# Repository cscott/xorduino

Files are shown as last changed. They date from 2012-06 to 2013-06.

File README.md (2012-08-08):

This is an Open Hardware peripheral for the OLPC XO-1/1.5/1.75/4.

The files are created using Eagle 6.2.0 on Linux and the SparkFun footprint
libraries.

Strong inspiration drawn from the following Open Hardware designs (thanks for
sharing!):
* The Arduino Leonardo (arduino-compatible ATmega32U4 design)
* SparkFun's ATmega32U4 breakout <http://www.sparkfun.com/products/11117>
  for figuring out which parts of the Leonardo design are actually
  mandatory
* SparkFun's Scratch Sensor Board-compatible PicoBoard
    <http://www.sparkfun.com/products/10311>

Some notes:

0. This board integrates Arduino, Scratch Sensor Board, and turtle robot
   functionality.  There are many optional parts: if you want to build
   just the Arduino, you may; if you want to populate the robot functionality
   but not the sensor board, that's fine, too.  If you populate the
   peripherals but not the ATmega32u4 processor, this makes a splendid
   "shield" for the XO Stick -- one way to amortize the cost of
   the robot functionality is to have just one XOrduino-bot shield per
   classroom, while still giving the kids their own XO Stick "brains"
   which they can mount on top of it.

    The "bot" features of the board include a current-limited motor driver,
   two bump switches at the front of the board, and two optical sensors
   for measuring motor rotation, allowing the user to write code like
   "rotate left 90 degrees" instead of "rotate left 2 seconds", which
   experimentally kids find much harder to understand.  The XOrduino
   board mounts on a Tamiya Twin Motor Gearbox (part #70097), and there's
   a mounting hole for a ~25mm long standoff to serve as a front skid.

    The motors are set up to draw 1A max, which matches the power source
   ability of the XO's USB ports.  The USB standard only allows 500mA
   draw, which would require adjusting F1 and RN7.

1. Many of the Leonardo design's components are optional in a
   lowest-possible-cost design, for a number of different reasons:
   a) USB port protection which is already included on the XO
      motherboard,
   b) ESD and protection diodes (helpful but not required),
   c) bypass caps and ferrites for less noise on analog signals
      (helpful but not required).
   Wherever possible I've included the pads anyway, so that less
   budget-conscious users can populate these components.  At times
   this has required jumper traces which you need to cut if you
   decide to populate the optional components.

2. I eliminated the multi-way 3.3V/5V internal/external power supply
   functionality of the Arduino to save cost.  The XOrduino is 5V
   only, powered by the USB port.  The Arduino "3.3V" pin on the
   shield connector is left disconnected.  I've replaced this with
   a lower cost step-up regulator, allowing "bot" users to power
   the XOrduino with a 3-cell (4.5v) battery pack.  Again, all
   these components are optional: the XOrduino will run fine
   powered by its USB tether.

3. The first version of this board used a large number of through-hole
   parts.  This revision is less afraid of surface mount parts (since
   the ATmega32U4 is only available in an SMT package anyway), which
   save board space and lower BOM cost.  I'm attempting to make the
   XOrduino local-assembly-friendly, so I surface mount footprints are
   as large as possible: all discrete components are 0805 or larger.
   Like the XO Stick, this has been routed as a two layer board to
   lower reproduction costs, although if you fabricate with a 4-layer
   board you will get more robust power and ground planes.

    One possibly-controversial change in this version is to use
   surface mount resistor arrays to reduce part count and BOM cost;
   they may turn out to be too small to hand assemble.  We'll see.

4. I made this Scratch Sensor Board compatible.  Even though many of
   the scratch sensors are redudant on the XO (it has a microphone
   already, and the XO-1.75 includes an ambient light sensor), they
   gain new relevance in the "turtle bot" mode -- they make it easy to
   build a standalone robot which is "afraid of light", "stops when
   you clap", etc.  The scratch community has a large number of
   interesting examples based around the Scratch Sensor
   Board/Picoboard, many of which can use the 4 additional channels
   provided by the XOrduino ("color etch-a-sketch", for example, with
   knobs for X, Y, color, and line width).  I used 3.5mm jacks instead
   of the Picoboard-standard 2.5mm jacks in order to be compatible
   with probes built for the XO; I hope that was a good choice.

    See https://github.com/osbock/ScratchSensors for an arduino sketch
   to support the Scratch Sensor board functionality; it might be nicer
   to integrate this into the bootloader so that it's "always there".

5. There's a USB plug integrated with the PCB with break-off tabs to
   increase the thickness to the USB standard 1.6mm.  There are pads
   for a through-hole USB mini-B connector and a more-standard surface
   mount USB micro-B connector, but they are rather expensive (~$1).

    When the discrete connector is populated, it leaves the USB
   signals and power/gnd exposed on big metal tabs, which could be
   non-ideal.  Certainly you shouldn't plug in to more than one jack
   at a time.

  -- C. Scott Ananian, 2012-06-09, revised 2012-07-30, 2012-08-08.

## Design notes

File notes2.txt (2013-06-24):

Notes/todo for XOrduino2 design:
.- drill second mounting hole
.- drill skid hole
   3mm hole, 1mm front front end, centered (53mm wide, center is 26.5mm)
   make hole bigger to accomodate 6-32 screw: digikey 1903EK-ND
   slightly longer would be better
   existing holes are 3.2mm; .12598425"
   24438K-ND is $0.4101 (qty 100), M3, 25mm long
x- wire up L293
x- wire up 7805
.- wire up limit switches
.- wire up optoisolators
research TCRT1000, we only need 2-3mm now. slightly taller shoulder?
downward looker? paint top of gear.
.- servo connection? 4.8V servo
x- bidirectional led instead of ambient light sensor
.- remove external pull-up, use internal pullup, change to 3.5mm jack
   to be compatible w/ XO
.- current limit should be 300-400mA per motor, change USB fuse to match
   XO limit is 1.0-1.1A. (USB spec is 500mA, though)
.- no-hole version of bumper switch footprint
.- switch to array of solder jumpers for A0-A5 routing
.- put via in solder jumper footprint?
.- rotate motor power 90 degrees?
.- via in switcher
.- shift ICP jack to right
.- SMT LEDs? 0805, @ $0.06 red/green
.- look at diode placement
.- move switcher to front side?
.- add variant of usb micro w/ breaks out to vias?
.- alt version of 3mm LED w/ straight line on one side
x- split current limit resistors
.- minimize # of solder jumpers
.- battery input is Vin, use something else (Vm) for wire-or'ed signal.
.- change width of polygons to non-zero (switcher done, h-bridge still to do)
x- remove center dot on uC footprint
.- fault LED SMT and placed next to resistor on top of bridge
.- swap ISP and photosensor location
.- fix usb micro broken out
 - divide up tab area into 4 equal parts (2.1" tall, usb is .48")
   measure width of router bit... looks like we only have .04" kerf =(
x- bottom | top - seems to be best?
.- fixup silkscreen on USB mini footprint (do DRC w/ solder mask enabled)
 - fixup 1n4148 silkscreen and z1/z2 silkscreen
 - power switch

battery backup circuit:
 dedicated: 	ICL7673CPAZ-ND ($1.40), 296-10879-1-ND ($1.50)
http://www.linear.com/product/LTC4411
LTC4411ES5#TRMPBF-ND ($3.12) linear says $1.66 qty 1000
(see also LTC4410 w/ external FET)
something like LP38693, the VEN signal can be tied to VIN
 XXX but really want VEN = !VUSB

better: just put diode between 5v regulator and 5v supply, run at 4.8V
from battery, run at 5v w/ usb power. (or run at 3.3V from battery?)

or even better: just run i/o at 4.5v when running from usb power?
(schottkey diode between vusb and +5V)
run everything from 6V from battery (no regulator)
are there quad schottkey diodes? SD103ATW-FDICT-ND $0.2039 qty 100
  (0.08 premium)

ATmega32U4 uses 16mA max
motor driver cuts out at 2.6V
power option 1:
 4.5V battery, normal diode-OR, NJU7261U50-TE1CT-ND step up (1-5V) $0.40 qty 100
               two diodes for 6V battery version
               run VM from diode-OR voltage (ie, 3.9V or 5.8V)
 needs 22uF cap x 2, 100uH inductor 587-2048-1-ND (50mA, $0.0665 qty 100)
                                or  587-2055-1-ND (80mA, $0.0980 qty 100)
    battery holder wire lead BC3AAW-ND $1.06 qty 100
 
 alternatively 	1028-1077-1-ND (richtek RT9261A-50GB) is $0.65 qty 100
  needs 100uH inductor, 1N5819 diode, and 22uF cap.

new motor driver! 296-29434-1-ND ($2.204 qty 100)
 (also keep an eye on 869-1287-1-ND ($1.7718 qty 100)
                  and 296-28165-1-ND (DRV8830) )
usb micro: $0.30320 SMD
609-4050-1-ND $0.505 SMD more solderable.  no good thru-hole version

to buy:
 digikey:
  wirewrap tool 	K105-ND
  30 awg wire stripper JIC-2030-ND (pliers form, $9.10)
                       K512-ND (cut and strip tool, $52.50)
                       K503-ND ($34.60)
  ATTINY861A-PU-ND
  new photosensors
    QRE1113GRCT-ND (smd)
    QRE1113-ND (4-DIP)
  3mm spacer? 24438K-ND
    H744-ND (M3x12 screw)
  more stackable headers?
  usb micro connector 609-4050-1-ND
  motor driver 296-29434-1-ND
  3x Schottkey: SD103ATW-FDICT-ND
  screw terminal A98334-ND
  single schottkey for prototyping?
   LSM115JE3/TR13CT-ND has Vf of 0.22 V
  new 1/8" jack: CP1-3523N-ND
 sparkfun:
  tooth wheels?
  flux pen
  solder

optosensor: consider:
751-1031-ND $0.7424 (qty 100) -- original part
QRE1113GRCT-ND $0.5838 (qty 100)
475-1239-1-ND $1.2254 (qty 100) -- logic level out
ambient light sensor
1080-1019-ND $0.29760 (qty 100) good match for 50uA light current of original part

--------------------
Partlist

Exported from XOrduino2.sch at 7/30/12 12:38 PM

EAGLE Version 6.2.0 Copyright (c) 1988-2012 CadSoft

Assembly variant: 

Part     Value             Device               Package               Library                    Sheet DigiKey Package Price (qty 100)

C1       18p               CAP0805                        0805                           SparkFun-Passives          1 311-1102-1-ND 0805" $0.02860
C2       18p               CAP0805                        0805                           SparkFun-Passives          1
C3       100n              CAP0805                        0805                           SparkFun-Passives          1 311-1361-1-ND 0805" $0.01410
C4       100n              CAP0805                        0805                           SparkFun-Passives          1
C5       100n              CAP0805                        0805                           SparkFun-Passives          1
C6       100n              CAP0805                        0805                           SparkFun-Passives          1
C7       100n              CAP0805                        0805                           SparkFun-Passives          1
C8       1uF               CAP0805                        0805                           SparkFun-Passives          1 445-1589-1-ND 0805" $0.01150
C9       1uF               CAP0805                        0805                           SparkFun-Passives          1
C10      0.22uF            CAP0805                        0805                           SparkFun-Passives          1 587-1306-1-ND 0805" $0.03800
C11      0.33uF            CAP0805                        0805                           SparkFun-Passives          1 445-1356-1-ND 0805" $0.06300 (!)
C12      10uF              CAP0805                        0805                           SparkFun-Passives          2 445-1371-1-ND 0805" $0.04990
C13      22uF              CAP1206                        1206                           SparkFun-Passives          1 587-1356-1-ND 1206" $0.10000
C14      22uF              CAP1206                        1206                           SparkFun-Passives          2
C15      0.01uF            CAP0805                        0805                           SparkFun-Passives          2 490-1664-1-ND 0805" $0.01420
D1       1N4148            DIODE1N4148                    DIODE-1N4148                   SparkFun-DiscreteSemi      1 1N4148FS-ND, 200mA  DO-35 $0.03690
D2       1N4148            DIODE1N4148                    DIODE-1N4148                   SparkFun-DiscreteSemi      1
D3       1A Schottkey      DIODE-SCHOTTKY_                SMA-DIODE                      SparkFun-DiscreteSemi      2 641-1014-1-ND SMA  $0.15140
D4       1A Schottkey      DIODE-SCHOTTKY_                SMA-DIODE                      SparkFun-DiscreteSemi      2
F1       0ZCC0110FF2C 1.1A L-EUL1812                      L1812                          rcl                        1 507-1363-1-ND 1812" $0.16150
                                                                                                                      S1012EC-40-ND       $0.37800 (1x40, for H1/H2/H3/H4/JP12)
H1       10x1F-H8.5        PINHD-1X10                     1X10                           SmartPrj                   1
H2       8x1F-H8.5         PINHD-1X8                      1X08                           SmartPrj                   1
H3       8x1F-H8.5         PINHD-1X8                      1X08                           SmartPrj                   1
H4       6x1F-H8.5         PINHD-1X6                      1X06                           SmartPrj                   1
H5       ICSP              PINHD-2X3                      2X03                           SmartPrj                   1 609-3218-ND         $0.1778
J1       2.5mm             AUDIO-JACK                     MJ-3523-SMT                    xorduino                   1 CP-3523MJCT-ND      $0.79610
J2       2.5mm             AUDIO-JACK                     MJ-3523-SMT                    xorduino                   1
J3       2.5mm             AUDIO-JACK                     MJ-3523-SMT                    xorduino                   1
J4       2.5mm             AUDIO-JACK                     MJ-3523-SMT                    xorduino                   1
J5       Batt In           M02PTH                         1X02                           SparkFun-Connectors        2 BC3AAW-ND           $1.06000
J6       MOT R             M023.5MM                       SCREWTERMINAL-3.5MM-2          SparkFun                   2 A98036-ND           $0.18010
J7       MOT L             M023.5MM                       SCREWTERMINAL-3.5MM-2          SparkFun                   2
JP1      N/C               SOLDERJUMPERNOCONFLICT         SJ-2S-TRACE-NOCONFLICT         xorduino                   2 n/a
JP2      N/C               SOLDERJUMPERNOCONFLICT         SJ-2S-TRACE-NOCONFLICT         xorduino                   1
JP3      N/C               SOLDERJUMPERNOCONFLICT         SJ-2S-TRACE-NOCONFLICT         xorduino                   1
JP4      N/C               SOLDERJUMPERNOCONFLICT         SJ-2S-TRACE-NOCONFLICT         xorduino                   1
JP5      N/C               SOLDERJUMPERNOCONFLICT         SJ-2S-TRACE-NOCONFLICT         xorduino                   1
JP6      N/C               SOLDERJUMPERNOCONFLICT         SJ-2S-TRACE-NOCONFLICT         xorduino                   1
JP7      N/C               SOLDERJUMPERBOT-VIA-NOCONFLICT SJ-2S-BOT-TRACE-VIA-NOCONFLICT xorduino                   1
JP8      N/C               SOLDERJUMPERBOT-VIA-NOCONFLICT SJ-2S-BOT-TRACE-VIA-NOCONFLICT xorduino                   1
JP9      N/C               SOLDERJUMPERBOT-VIA-NOCONFLICT SJ-2S-BOT-TRACE-VIA-NOCONFLICT xorduino                   1
JP10     N/C               SOLDERJUMPERBOT-VIA-NOCONFLICT SJ-2S-BOT-TRACE-VIA-NOCONFLICT xorduino                   2
JP11     N/C               SOLDERJUMPERBOT-VIA-NOCONFLICT SJ-2S-BOT-TRACE-VIA-NOCONFLICT xorduino                   2
JP12     SERVO             M03PTH                         1X03                           SparkFun-Connectors        2 w/ H1/H2/H3/H4
L1       MH2029-300Y       WE-CBF_0805                    0805                           wuerth-elektronik          1 MH2029-300Y-ND    $0.0174 300 ohm bead ferrite (qty 4000)
L2       MH2029-300Y       WE-CBF_0805                    0805                           wuerth-elektronik          1
L3       100uH             INDUCTOR1007                   1007                           SparkFun-Passives          2 587-2055-1-ND (80mA) $0.0980
LED1     L Yellow          LED0805                        LED0805                        xorduino                   1 754-1135-1-ND $0.08450  (! use green instead)
LED2     TX Red            LED0805                        LED0805                        xorduino                   1 475-1415-1-ND $0.05900
LED3     RX Red            LED0805                        LED0805                        xorduino                   1
LED4     ON Green          LED0805                        LED0805                        xorduino                   1 475-1410-1-ND $0.05900 
LED5     FAULT Red         LED0805                        LED0805                        xorduino                   2 475-1415-1-ND $0.05900 (same as LED2/LED3)
MIC1     MIC9.7MM          MIC9.7MM                       MIC-9.7MM                      SparkFun                   1 102-1721-ND       $0.56930 (XXX: cheaper option?)
P1       10k               POT                            P091N                          xorduino                   1 987-1279-ND   $0.85500
Q1       ALS-PT204-6C/L177 ALS-PT204-6C/L177              LED3MM-KIT                     xorduino                   1 1080-1019-ND  $0.29760
R1       1M                RESISTOR0805-RES               0805                           SparkFun-Passives          1 311-1.0MARCT-ND $0.00770
R2       2.2k              RESISTOR0805-RES               0805                           SparkFun-Passives          1 311-2.2KARCT-ND $0.00770
R3       1k                RESISTOR0805-RES               0805                           SparkFun-Passives          2 A106056CT-ND $0.00580
RN1      22                RESISTOR-ARRAYCRA06S           CRA06S                         xorduino                   1 CRA6S822CT-ND $0.01480 (4x)
RN2      10k               RESISTOR-ARRAYCRA06S           CRA06S                         xorduino                   1 CRA6S810KCT-ND $0.01480
RN3      1k                RESISTOR-ARRAYCRA06S           CRA06S                         xorduino                   1 CRA6S81.0KCT-ND $0.01480
RN4      100k              RESISTOR-ARRAYCRA06S           CRA06S                         xorduino                   1 CRA6S8100KCT-ND $0.01480
RN5      100k              RESISTOR-ARRAYCRA06S           CRA06S                         xorduino                   2
RN6      220               RESISTOR-ARRAYCRA06S           CRA06S                         xorduino                   2 CRA6S8220CT-ND $0.01480 (4x)
RN7      1ohm 1/16W        4R-NEXB38V                     EXB38V                         resistor-dil               2 Y91R0CT-ND $0.03410 (4x1ohm)
SW1      RESET             TAC_SWITCHPTH                  TACTILE-PTH                    SparkFun-Electromechanical 1 450-1652-ND       $0.1114
SW2      6mm Button        TAC_SWITCHPTH                  TACTILE-PTH                    SparkFun-Electromechanical 1
SW3      LEFT BUMPER       SWITCH-SPDTV1-NOHOLES          SW-LEVER-V1-NOHOLES            xorduino                   2 EG4935-ND $0.50140
SW4      RIGHT BUMPER      SWITCH-SPDTV2-NOHOLES          SW-LEVER-V2-NOHOLES            xorduino                   2 EG4936-ND $0.50140
U1       ATMEGA32U4-XUAU   ATMEGA32U4-XUAU                TQFP44-PAD                     SmartPrj                   1 ATMEGA32U4-AU-ND  $3.36840
U2       LMV358            LMV358                         SO08                           SparkFun                   1 296-9571-1-ND     $0.15 8-SOIC
U3       NJU7261           NJU7261                        SOT89-5                        xorduino                   2 NJU7261U30-TE1CT-ND $0.40000
U4       DRV8833PWP        DRV8833PWP                     PWP16                          xorduino                   2 296-29434-1-ND $2.20400
U5       QRE1113GR         QRE1113GR                      QRE1113GR                      xorduino                   2 QRE1113GRCT-ND $0.58380
U6       QRE1113GR         QRE1113GR                      QRE1113GR                      xorduino                   2
X1       USBPCB            USBPCB                         USB-A-PCB                      SparkFun-Connectors        1 n/a
X2       USBMINIB          USBMINIB                       USB-MB-H2                      xorduino                   1 WM17115-ND        $1.1038 USB mini-B through hole
X3       USBMICROB-VIA     USBMICROB-VIA                  USB-MICROB-VIA                 xorduino                   1 609-4050-1-ND     $0.50500
Y1       16MHz             CRYSTALHC49US                  HC49US                         SparkFun-FreqCtrl          1 CTX1085-ND        $0.2320
Z1       CG0603MLC-05E     VARISTORCN0603                 CT/CN0603                      varistor                   1 CG0603MLC-05E-ND  $0.06916 5VDC 0603 ESD suppressor (qty 10,000)
Z2       CG0603MLC-05E     VARISTORCN0603                 CT/CN0603                      varistor                   1

misc:
3mm spacer 24438K-ND
2 of screws H744-ND (M3x12 screw)

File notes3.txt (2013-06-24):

Hall Sensor Board:
 AH180N-ZG-7DICT-ND is default part, thresh 35g (max 50g)
investigate:
 TCS10DLU(TE85L,F) ($.07 more), thresh 18g (max 25g) <- twice as good
   are footprints compatible?
http://www.kjmagnetics.com for magnets

v6:
- RN7 too close to skid screw hole
- U4 (motor driver) doesn't have pin1 mark
- missing 2 red LEDs LED2/LED3
- LED dot indicator is on wrong side; use the notation from bottom of LED
- unmask vias below motor driver and switcher
- L3 footprint could be larger
removed U1 from xorduino #2 (then replaced)
U3 wrong on BOM; coil wrong, too.
user switch makes it hard to insert wires in left hand screw terminal
taps on AISEN/BISEN to measure motor currents?
seeing 1.5v drop on optical sensor; max freq 83Hz (min period 12ms)
  probably design for 1ms min pulse time.
  small stripe / large stripe for direction? XX
  if we want direction we need another pair of sensors, w/ different phase

  a b c d == where a!=c, b!=d.  maybe just
    short long longer (a b c)
  forward = > > < > > <
  backward= < < > < < >
   in a/c states, need to be able to distinguish length of states for direction
  we could also assume that transitions are "rare"

  short LONG long SHORT -- using length to distinguish assumes
  constant speed (or places limits on speed of accel/decel, which may
  be reasonable) (lower is mark, upper is space)

weaker pullup for RN5?  can go to 150k at least.
 (digikey: 150k RN5, wire wrap, caps and inductors for power supply)
run board directly from 6V battery pack, maybe w/ diode?
jumper VUSB to VCCIO, jumper VCCIO to +5V.  Wire jumpers?

-----------------------
- Move USB PCB connector to bottom corner (near phone jacks), which lets
  you plug in to the vertical slot on the XO when it is closed (in
  "tablet mode")
- move light sensor to USB connector side of XOrduino so it is not
  shaded by backpack XO Stick.

- usb micro jack is just too small to reasonably hand solder
- move light sensor over to where usb micro jack is
- move usb tab connector to bottom corner
- nylon standoff at front, not conductive Al
- bottom standoff screw needs a touch of glue?
- rubber band around board to secure battery pack
- servo connector is close to pot connection and very similar.
  disambiguate for more reliable assembly?
- check wire gauge for screw terminal
- body of pot might short against USB mini connector.
  - move USB mini to place occupied by USB micro
    and move it back away from the edge of the board a hair
    so it's even w/ pcb board edge and doesn't interfere
    w/ pcb usb connector
.- u2 has stripe not dot
?- L3 footprint seems small
.- markings: 103 on RN2, 104 on RN4/5, 221 on RN6, 102 on RN3, 220 on
  RN1, 1.0 on RN7

.- XO Stick: label U2 with arduino pin names.
- remind people to email me their mailing address
- ask folks if they have an AVR programmer

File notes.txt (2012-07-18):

Notes on XOrduino v4 boards:
 - avoid tab on usb connector, move to body
 - N/C jumpers turned out N/O (scratch sensor board)
.- merge 5V and +5V nets
 - C5/C7 too close together (and too close to C9) & need polarity marks
 - C11/C13 needs polarity mark (or to be unpolarized)
 - flip RN3?
 - audio jack footprints are wrong.  and drill holes overlap for top&bottom
 - just use tip and sleeve(gnd) on audio jack (leave ring(s) disconnected)
   use 1/8" instead of 3/32"?
   digikey CP1-3523N-ND $0.39480 qty 100 (stereo, no switch)
 - right angle pot is right but don't need strain relief holes, need knob (shorter handle?)
.- mini USB jack silkscreen on wrong side
.- mini USB just a tiny bit too close to pcb plug
 - mounting hole clearances too small:
    
 - add front nose skid (near where audio jack currently sits?)
 - potentiometer footprint 
 - add light sensors and/or bumper switches somehow
   light sensors pointed at the wheels?
 - add labels to new arduino 1.0 pins (SCL/SDA above AREF)
 - add breakoff tabs to thicken USB plug (by reset pin, two deep)
 - solder spot under AVR is unnecessary
 - male header strip should be female for arduino headers
   1x S7004-ND (6 pin)
   2x S4008-ND (non-stock) or S7006-ND (8 pin)
   1x S7043-ND (10 pin) or S7008-ND (should be cheaper, but isn't)
 - ISP header needs pin 1 indication, label.
 - Yellow LEDs don't have a flat side!
 - add LED polarity silkscreen
 - remove solder mask on solder jumper center
 - replace 2x7 shorting header w/ 1x7 signal header and array of
   shorting jumpers

NOTE THAT ATmega32u4 should be placed upside down. (rotate it?)

TESTED: xorduino can be programmed w/ nothing mounted but the chip and
the ISP header.

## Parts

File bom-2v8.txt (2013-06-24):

Here's my suggested XO Stick and XOrduino BOMs, with just the bits
really necessary (not all the extras).

The XOrduino BOM was put together with Mitch Bradley's help.  Thanks!

Here is the XOrduino DigiKey BOM organized by sections.  You can paste
individual sections directly into the "Create New BOM (Text File
Import)" dialog.

-- Basic
2,311-1102-1-ND,C1 C2 - 18pF 0805
4,311-1361-1-ND,C2 C3 C4 C5 C6 - 100nF 0805
1,ATMEGA32U4-AU-ND,U1 - ATMEGA32U4-AU
1,445-1589-1-ND,C9 - 1uF
1,587-1356-1-ND,C13 22uF 1206
1,507-1363-1-ND,F1 - 6V 1.1A 1812 PTC Resettable Fuse
1,754-1135-1-ND,LED1 - LED yellow 0805
2,475-1415-1-ND,LED2 LED3 - LED red 0805
1,475-1410-1-ND,LED4 - LED green 0805
10,CRA6S822CT-ND,RN1 - 4x22R (1 required, minimum order is 10)
10,CRA6S810KCT-ND,RN2 - 4x10K (1 required, minimum order is 10)
10,CRA6S81.0KCT-ND,RN3 - 4x1K (1 required, minimum order is 10)
1,450-1652-ND,SW1 - tactile switch
1,CTX1085-ND,Y1 - 16MHz 18pF crystal
1,609-3550-ND,H1 - 10-pin female
2,609-3559-ND,H2 H3 - 8-pin female
1,609-3558-ND,H4 - 6-pin female
1,609-3218-ND,H5 - 3-pin 2-row header

-- Optional
1,311-1.0MARCT-ND,R1 - 1M 0805
1,1N4148FS-ND,D1 - 1N4148
1,445-1589-1-ND,C8 - 1uF 0805
2,L1 L2 - ferrite bead 30 ohm
1,WM17115-ND,X2 - USB mini-B connector
1,609-4050-1-ND,X3 - USB micro-B connector
2,CG0603MLC-05E-ND,Z1 Z2 - ESD suppressor

-- Scratch Sensor
1,311-1361-1-ND,C7 - 100nF 0805 20%
1,587-1306-1-ND,C10 - .22uF 0805
1,445-1356-1-ND,C11 - .33uF 0805
1,1N4148FS-ND,D2 - 1N4148
1,102-1721-ND,MIC1 - 9.7mm microphone
1,987-1279-ND,P1 - 9mm Pot
1,1080-1019-ND,Q1 - ambient light sensor
1,311-2.2KARCT-ND,R2 - 2.2K 0805
10,CRA6S8100KCT-ND,RN4 - 4x100K (1 required, minimum order is 10)
1,450-1652-ND,SW2 - tactile switch
1,296-9571-1-ND,U2 - LMV358 SOIC-8
4,CP-3523MJCT-ND,J1 J2 J3 J4 3.5mm audio jacks

-- Robot
(for a simple robot base, use just these parts, plus the mechanical
 parts below, plus H1/H2/H3/H4 from above)
1,445-1371-1-ND,C12 - 10uF 0805
1,GRM216R71H103KA01D,C15 - .01u 0805 X7R
1,S1012EC-40-ND,JP12 - 3-pin 1-row header
1,475-1415-1-ND,LED5 - LED red 0805
1,A106056CT-ND,R3 - 1K
10,CRA6S8100KCT-ND,RN5 - 4x100K (1 required, minimum order is 10)
10,CRA6S8220CT-ND,RN6 - 4x220R (1 required, minimum order is 10)
1,296-29434-1-ND,U4 - DRV8833PWP motor driver
2,QRE1113GRCT-ND,U5 U6 - light sensor
2,A98036-ND,J6 J7 screw terminal blocks
1,Y91R0CT-ND,RN7 4x1R
1,EG4935-ND,SW3 right snap switch
1,EG4936-ND,SW4 left snap switch

-- Mechanical
1,24438K-ND,Front Skid
2,H744-ND,Front Skid Screw (minimum 100)

-- Power Supply
XXX NOTE that the step-up power supply on XOrduino2 v8 DOES NOT WORK XXX
    (the coil L3 appears to be saturating at the currents used)
    These are the parts required to populate this part of the board, but
    don't buy them unless you're feeling adventurous. Use USB power instead.
2,641-1014-1-ND,D3 D4 - 1A Schottky SMA
1,587-2055-1-ND,L3 - 100uH 1007
1,587-1356-1-ND,C14 - 22u 1206
1,BC3AAW-ND,J5 - battery holder
1,NJU7261U50-TE1CT-ND,U3 boost regulator

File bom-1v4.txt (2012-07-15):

Partlist (v4)

alternative to 478-5741-ND: 478-3192-ND ($0.11)
xx: look at using the RC suffixed version of the ATMEGA32U4, avoids need for crystal
ie, ATMEGA32U4RC-AU-ND (low speed USB only)
alternative to 4608X-2-102LF-ND: 987-1254-ND
rename C13 to C12
U7's price is ridiculous
rename R7/R8/R9 to R4/R2/R3

REQUIRED:
Part     Value              Device            Package              Library                    Digikey   Cost (qty 100)
C1       100n               CAPPTH            CAP-PTH-SMALL        SparkFun-Passives          478-5741-ND           $0.09450 (.100" lead spacing)
C2       100n               CAPPTH            CAP-PTH-SMALL        SparkFun-Passives          478-5741-ND           $0.09450 (.100" lead spacing)
C3       18p                CAPPTH            CAP-PTH-SMALL        SparkFun-Passives          BC1004CT-ND           $0.11760 (.100" lead spacing)
C4       18p                CAPPTH            CAP-PTH-SMALL        SparkFun-Passives          BC1004CT-ND           $0.11760 (.100" lead spacing)
C6       100n               CAPPTH            CAP-PTH-SMALL        SparkFun-Passives          478-5741-ND           $0.09450 (.100" lead spacing)
C7       1uF                CAPPTH            CAP-PTH-SMALL        SparkFun-Passives          P5174-ND              $0.06800  (.08" lead spacing)
C8       10uF               CAP_POLPTH2       CPOL-RADIAL-10UF-25V SparkFun-Passives          399-6100-ND           $0.05350  (.08" lead spacing)
C9       100n               CAPPTH            CAP-PTH-SMALL        SparkFun-Passives          478-5741-ND           $0.09450 (.100" lead spacing)
F1       MF-MSMF050-2 500mA L-EUL1812         L1812                rcl                        MF-MSMF050-2CT-ND $0.1475 500mA 15V fuse 1812 footprint 
L        Yellow             LED3MM            LED3MM               led                        754-1212-ND       $0.08250 3mm T1 yellow
RX       Yellow             LED3MM            LED3MM               led                        754-1218-ND       $0.07150 3mm T1 red
TX       Yellow             LED3MM            LED3MM               led                        754-1218-ND       $0.07150 3mm T1 red
ON       Green              LED3MM            LED3MM               led                        754-1217-ND       $0.07150 3mm T1 green
R8       22                 RESISTORAXIAL-0.3 AXIAL-0.3            SparkFun-Passives          CF14JT22R0CT-ND   $0.02190
R9       22                 RESISTORAXIAL-0.3 AXIAL-0.3            SparkFun-Passives          CF14JT22R0CT-ND   $0.02190
RN2      10k                E3RP              SIL6                 resistor-sil               4606X-2-103LF-ND  $0.08440 3x10k isolated, 6-SIP 
RN4      1k                 E4RP              SIL8                 resistor-sil               4608X-2-102LF-ND  $0.11320  4x1k isolated, 8-SIP 
S1       RESET 6mm          TAC_SWITCHPTH     TACTILE-PTH          SparkFun-Electromechanical 450-1652-ND       $0.1114
U1       ATMEGA32U4-XUAU    ATMEGA32U4-XUAU   TQFP44-PAD           SmartPrj                   ATMEGA32U4-AU-ND  $3.36840
Y1       16MHz HC49,18pF    CRYSTALHC49US     HC49US               SparkFun-FreqCtrl          CTX1085-ND        $0.2320

OPTIONAL:
Part     Value              Device            Package              Library                    Sheet

C5       1uF                CAPPTH            CAP-PTH-SMALL        SparkFun-Passives          P5174-ND              $0.06800  (.08" lead spacing)
C10      0.1uF              CAPPTH            CAP-PTH-SMALL        SparkFun-Passives          478-5741-ND           $0.09450 (.100" lead spacing)
C11      0.22uF             CAPPTH            CAP-PTH-SMALL        SparkFun-Passives          P821-ND               $0.08020  (.06"/1.5mm)
C13      0.33uF             CAPPTH            CAP-PTH-SMALL        SparkFun-Passives          P822-ND               $0.08020  (.06"/1.5mm)
D1       1N4148             DIODE1N4148       DIODE-1N4148         SparkFun-DiscreteSemi      1N4148FS-ND           $0.03690 (DO-35)
D2       1N4148             DIODE1N4148       DIODE-1N4148         SparkFun-DiscreteSemi      1N4148FS-ND           $0.03690 (DO-35)
H1       ICSP               PINHD-2X3         2X03                 SmartPrj                   609-3218-ND           $0.1778
J1       10x1F-H8.5         PINHD-1X10        1X10                 SmartPrj                   1
J2       8x1F-H8.5          PINHD-1X8         1X08                 SmartPrj                   1
J3       8x1F-H8.5          PINHD-1X8         1X08                 SmartPrj                   1
J4       6x1F-H8.5          PINHD-1X6         1X06                 SmartPrj                   1
                                                                                              S1012EC-40-ND         0.37800 (1x40, for J1/J2/J3/J4)
J5       2.5mm              AUDIO-JACKSMD     STEREOJACK2.5MM_SMD  SparkFun                   CP-2523MJCT-ND
J6       2.5mm              AUDIO-JACKSMD     STEREOJACK2.5MM_SMD  SparkFun                   CP-2523MJCT-ND
J7       2.5mm              AUDIO-JACKSMD     STEREOJACK2.5MM_SMD  SparkFun                   CP-2523MJCT-ND
J8       2.5mm              AUDIO-JACKSMD     STEREOJACK2.5MM_SMD  SparkFun                   CP-2523MJCT-ND
L1       MH2029-300Y        WE-CBF_0805       0805                 wuerth-elektronik          MH2029-300Y-ND    $0.0174 300 ohm bead ferrite (qty 4000)
L2       MH2029-300Y        WE-CBF_0805       0805                 wuerth-elektronik          MH2029-300Y-ND    $0.0174 300 ohm bead ferrite (qty 4000)
R1       1M                 RESISTORAXIAL-0.3 AXIAL-0.3            SparkFun-Passives          S1MQCT-ND         $0.02280
R7       2.2k               RESISTORAXIAL-0.3 AXIAL-0.3            SparkFun-Passives          CF14JT2K20CT-ND   $0.02190
RN1      10k                GE05RP            SIL6                 resistor-sil               4606X-1-103LF-ND  $0.08440 5x10k bussed, 6-SIP
RN3      100k               E3RP              SIL6                 resistor-sil               4606X-2-104LF-ND  $0.08440 3x100k isolated, 6-SIP
S2       6mm Button         TAC_SWITCHPTH     TACTILE-PTH          SparkFun-Electromechanical 450-1652-ND       $0.1114  6mm
U7       TEMT6000           TEMT6000          TEMT6000-SEN         SparkFun                   751-1055-1-ND     $0.90450
U8       LMV358IDR          LMV358            SO08                 SparkFun                   296-9571-1-ND     $0.15 8-SOIC
U9       MIC9.7MM           MIC9.7MM          MIC-9.7MM            SparkFun                   102-1721-ND       $0.56930
U10      10k                POT               ALPS_POT             SparkFun-Electromechanical 987-1276-ND       $0.46
X2       USB                USB               USB-MB-H2            xorduino                   WM17115-ND        $1.1038 USB mini-B through hole
Z1       CG0603MLC-05E      VARISTORCN0603    CT/CN0603            varistor                   CG0603MLC-05E-ND  $0.06916 5VDC 0603 ESD suppressor (qty 10,000)
Z2       CG0603MLC-05E      VARISTORCN0603    CT/CN0603            varistor                   CG0603MLC-05E-ND  $0.06916 5VDC 0603 ESD suppressor (qty 10,000)

OTHER:
JP2      N/C                SOLDERJUMPERTRACE SJ_2S-TRACE          SparkFun-Passives          1
JP3      N/C                SOLDERJUMPERTRACE SJ_2S-TRACE          SparkFun-Passives          1
JP4      N/C                SOLDERJUMPERTRACE SJ_2S-TRACE          SparkFun-Passives          1
JP5      N/C                SOLDERJUMPERTRACE SJ_2S-TRACE          SparkFun-Passives          1
JP6      Sensor Routing     JP7QES            JP7QS                xorduino                   1
X1       USBPCB             USBPCB            USB-A-PCB            SparkFun-Connectors        1

=========

RN4 alternate is: 987-1254-ND      $0.11390
C3/C4 alternate is 1428PH-ND             $0.11730 (.250" lead spacing)

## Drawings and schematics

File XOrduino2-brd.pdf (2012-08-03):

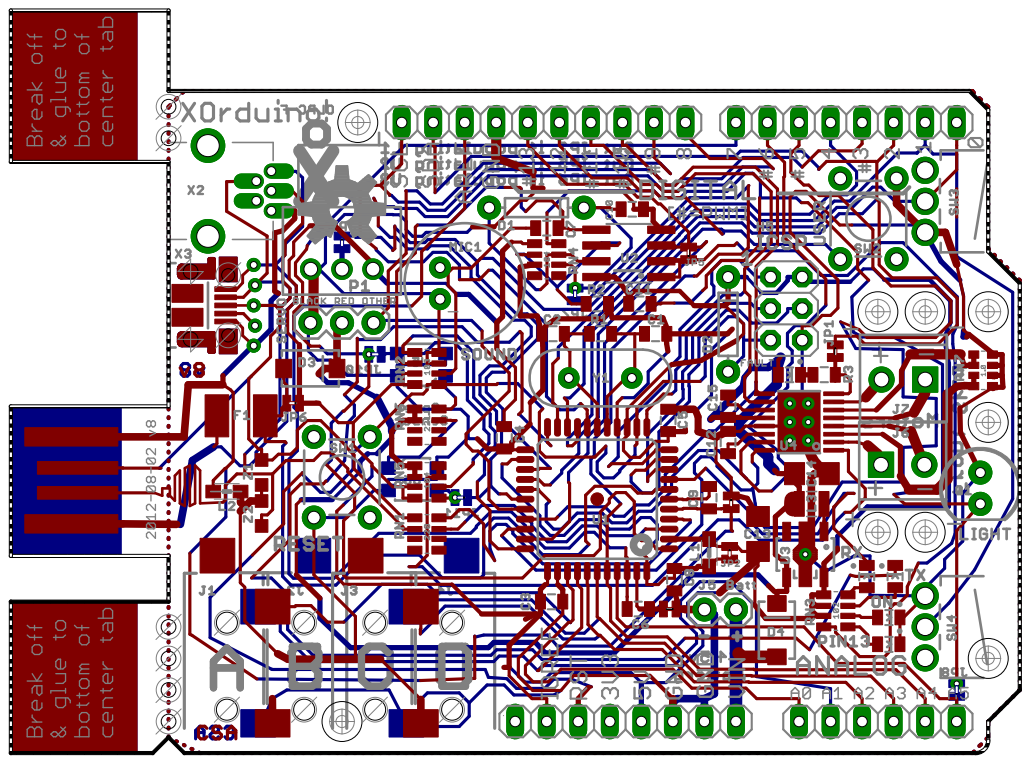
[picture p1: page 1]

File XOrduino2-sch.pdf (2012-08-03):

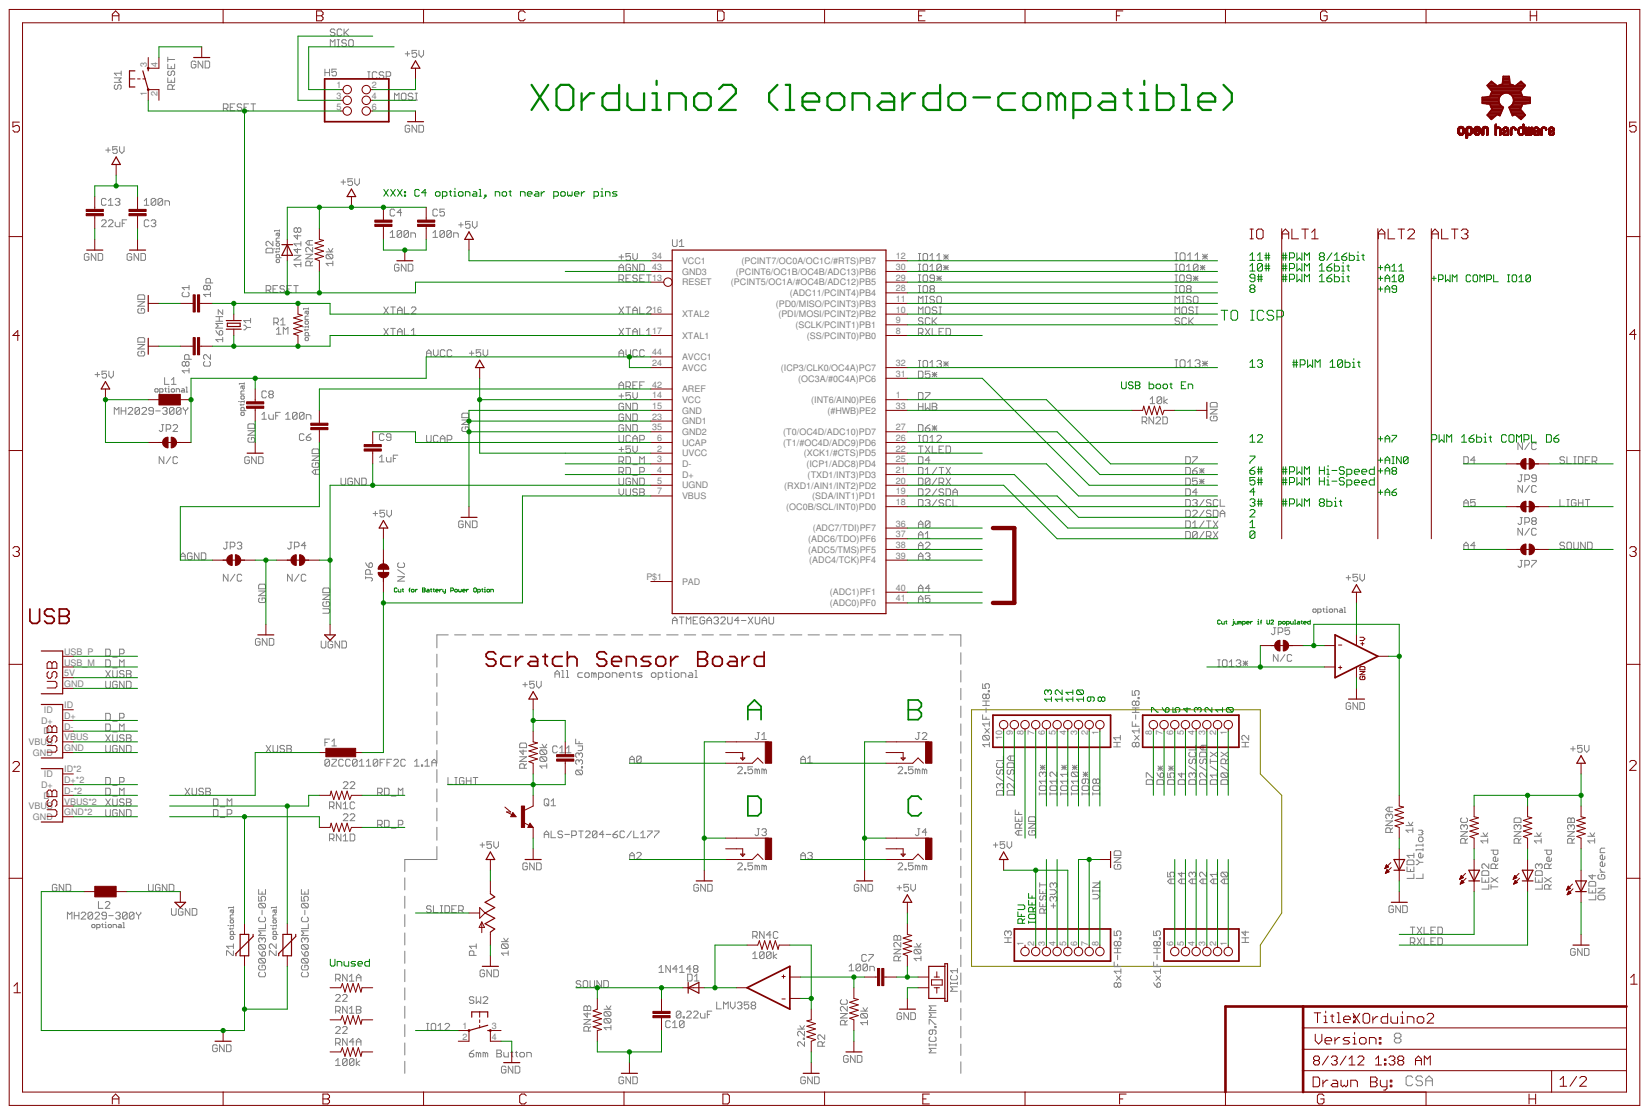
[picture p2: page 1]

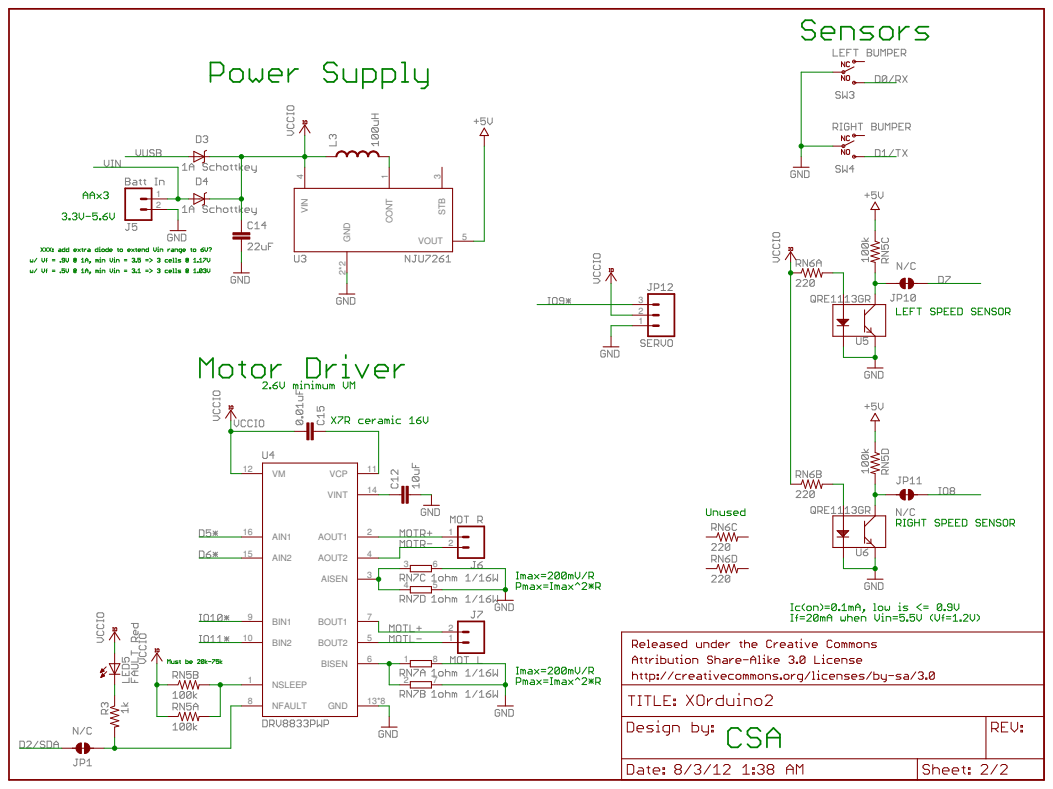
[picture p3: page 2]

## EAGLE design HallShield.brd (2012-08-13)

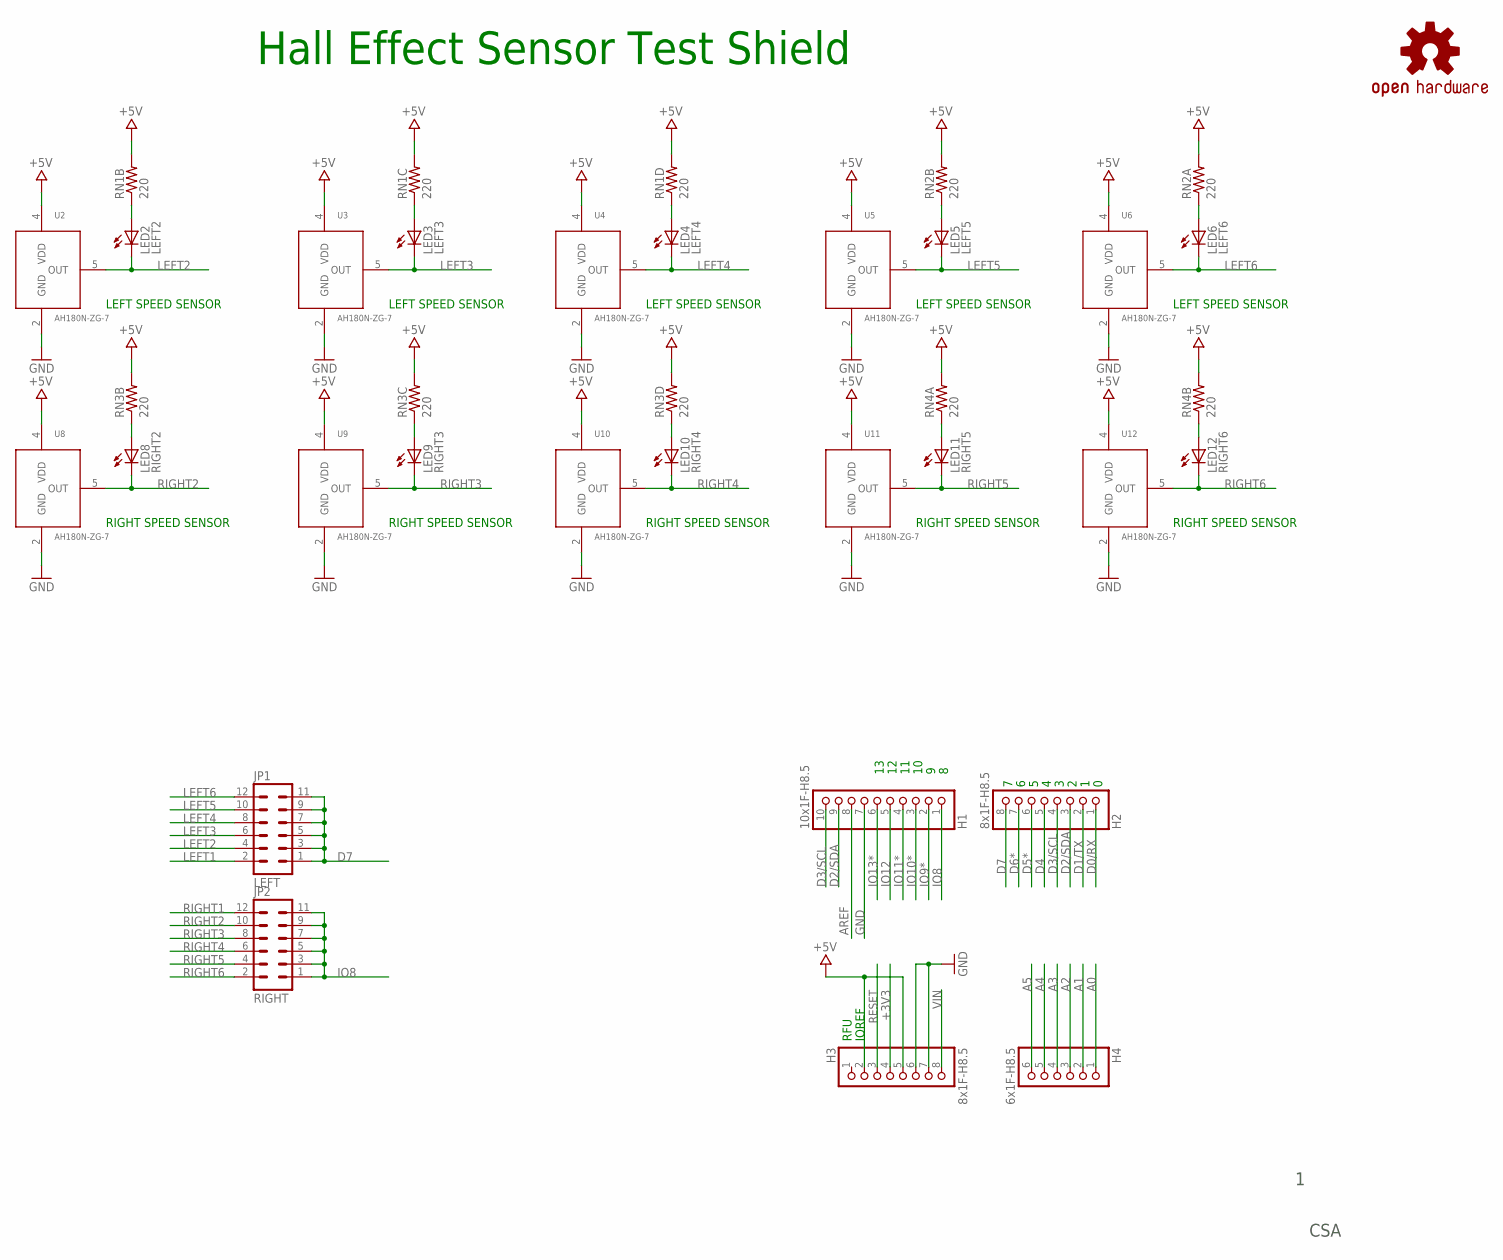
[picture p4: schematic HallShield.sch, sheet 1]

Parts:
H1: 10x1F-H8.5; 1X10
H2, H3: 8x1F-H8.5; 1X08
H4: 6x1F-H8.5; 1X06
JP1: LEFT; MA06-2
JP2: RIGHT; MA06-2
LED2: LEFT2; LED0805
LED3: LEFT3; LED0805
LED4: LEFT4; LED0805
LED5: LEFT5; LED0805
LED6: LEFT6; LED0805
LED8: RIGHT2; LED0805
LED9: RIGHT3; LED0805
LED10: RIGHT4; LED0805
LED11: RIGHT5; LED0805
LED12: RIGHT6; LED0805
RN1, RN2, RN3, RN4: 220; CRA06S
U2, U3, U4, U5, U6, U8, U9, U10, U11, U12: AH180N-ZG-7; SOT553
U$5: OSHW-LOGOL; OSHW-LOGO-L

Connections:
+3V3: H3.4
+5V: H3.2, H3.5, RN1.5 (2), RN1.6 (2), RN1.7 (2), RN2.7 (2), RN2.8 (2), RN3.5 (2), RN3.6 (2), RN3.7 (2), RN4.7 (2), RN4.8 (2), U2.4 (VDD), U3.4 (VDD), U4.4 (VDD), U5.4 (VDD), U6.4 (VDD), U8.4 (VDD), U9.4 (VDD), U10.4 (VDD), U11.4 (VDD), U12.4 (VDD); also elsewhere on the board
A0: H4.1
A1: H4.2
A2: H4.3
A3: H4.4
A4: H4.5
A5: H4.6
AREF: H1.8
D0/RX: H2.1
D1/TX: H2.2
D2/SDA: H1.9, H2.3
D3/SCL: H1.10, H2.4
D4: H2.5
D5*: H2.6
D6*: H2.7
D7: H2.8, JP1.1, JP1.3, JP1.5, JP1.7, JP1.9, JP1.11
GND: H1.7, H3.6, H3.7, U2.2 (GND), U3.2 (GND), U4.2 (GND), U5.2 (GND), U6.2 (GND), U8.2 (GND), U9.2 (GND), U10.2 (GND), U11.2 (GND), U12.2 (GND); also elsewhere on the board
IO8: H1.1, JP2.1, JP2.3, JP2.5, JP2.7, JP2.9, JP2.11
IO9*: H1.2
IO10*: H1.3
IO11*: H1.4
IO12: H1.5
IO13*: H1.6
LEFT1: JP1.2; also elsewhere on the board
LEFT2: JP1.4, LED2.C, U2.5 (OUT)
LEFT3: JP1.6, LED3.C, U3.5 (OUT)
LEFT4: JP1.8, LED4.C, U4.5 (OUT)
LEFT5: JP1.10, LED5.C, U5.5 (OUT)
LEFT6: JP1.12, LED6.C, U6.5 (OUT)
unnamed: LED2.A, RN1.2 (1)
unnamed: LED3.A, RN1.3 (1)
unnamed: LED4.A, RN1.4 (1)
unnamed: LED5.A, RN2.2 (1)
unnamed: LED6.A, RN2.1
unnamed: LED8.A, RN3.2 (1)
unnamed: LED9.A, RN3.3 (1)
unnamed: LED10.A, RN3.4 (1)
unnamed: LED11.A, RN4.1
unnamed: LED12.A, RN4.2 (1)
RESET: H3.3
RIGHT1: JP2.12; also elsewhere on the board
RIGHT2: JP2.10, LED8.C, U8.5 (OUT)
RIGHT3: JP2.8, LED9.C, U9.5 (OUT)
RIGHT4: JP2.6, LED10.C, U10.5 (OUT)
RIGHT5: JP2.4, LED11.C, U11.5 (OUT)
RIGHT6: JP2.2, LED12.C, U12.5 (OUT)
VIN: H3.8

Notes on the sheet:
Hall Effect Sensor Test Shield
IOREF
RFU
CSA
LEFT SPEED SENSOR
RIGHT SPEED SENSOR

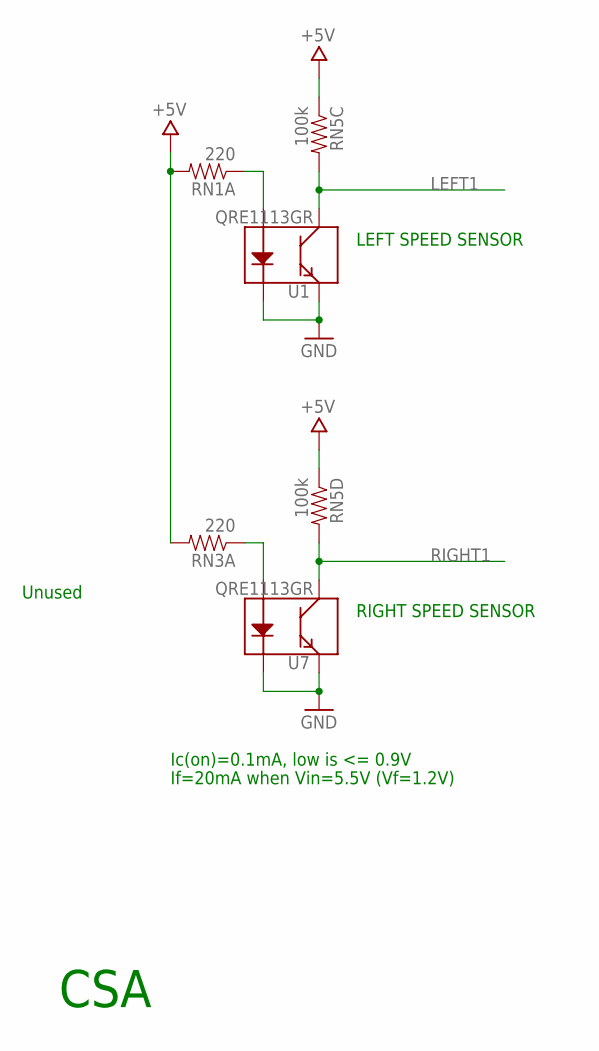
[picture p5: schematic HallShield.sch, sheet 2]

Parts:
RN1, RN3: 220; CRA06S
RN5: 100k; CRA06S
U1, U7: QRE1113GR

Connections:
+5V: RN1.8 (2), RN3.8 (2), RN5.3 (1), RN5.4 (1); also elsewhere on the board
GND: U1.2 (K), U1.4 (E), U7.2 (K), U7.4 (E); also elsewhere on the board
LEFT1: RN5.6 (2), U1.3 (C); also elsewhere on the board
RIGHT1: RN5.5 (2), U7.3 (C); also elsewhere on the board
U5_ANODE: RN1.1, U1.1 (A)
U6_ANODE: RN3.1, U7.1 (A)

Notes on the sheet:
LEFT SPEED SENSOR
RIGHT SPEED SENSOR
If=20mA when Vin=5.5V (Vf=1.2V)
Ic(on)=0.1mA, low is <= 0.9V
Unused
CSA

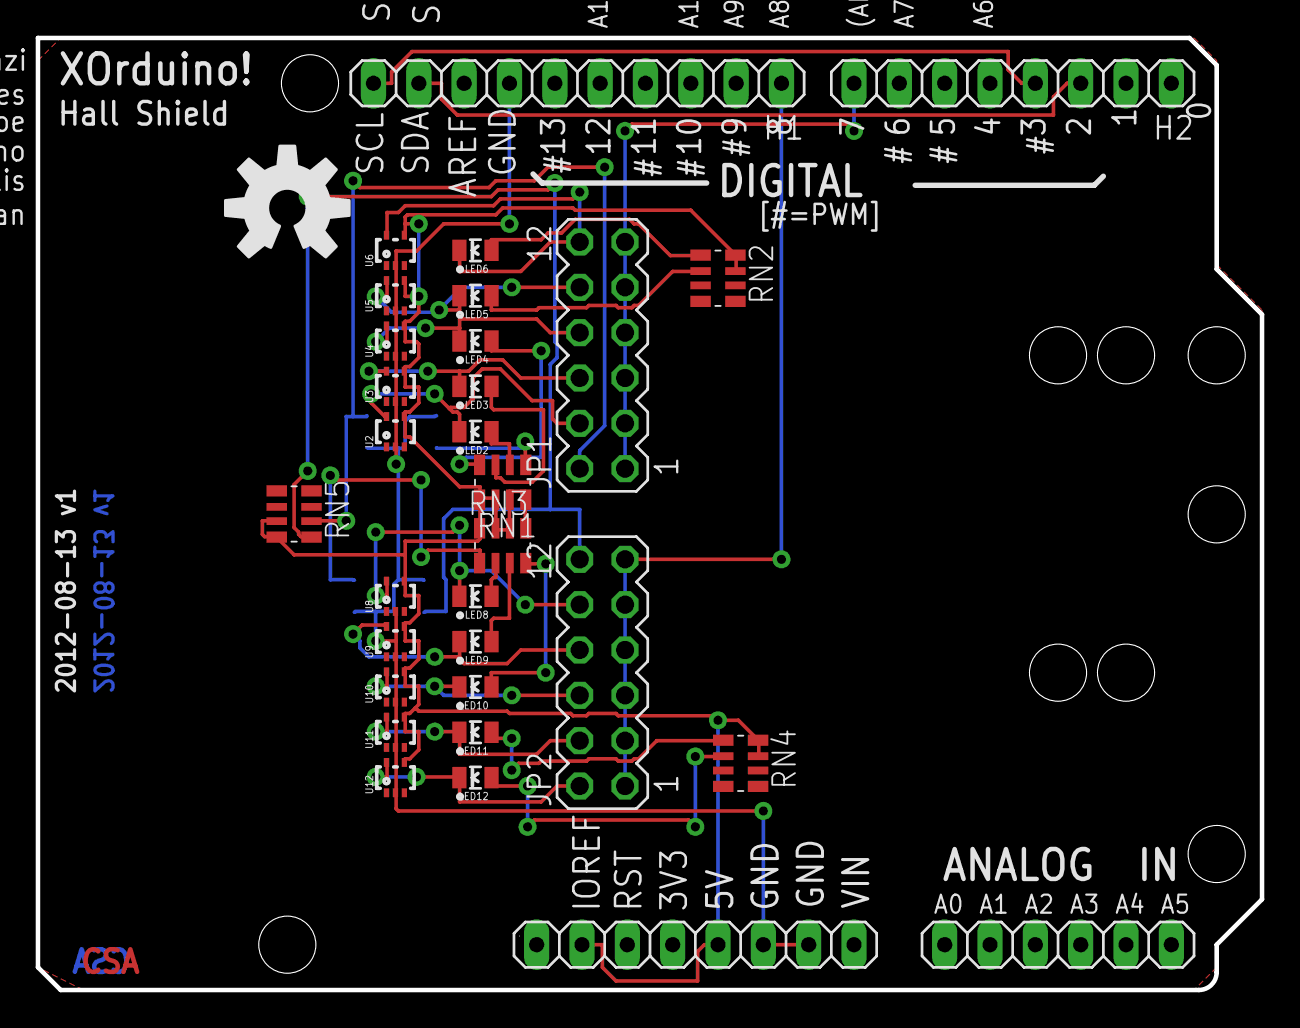
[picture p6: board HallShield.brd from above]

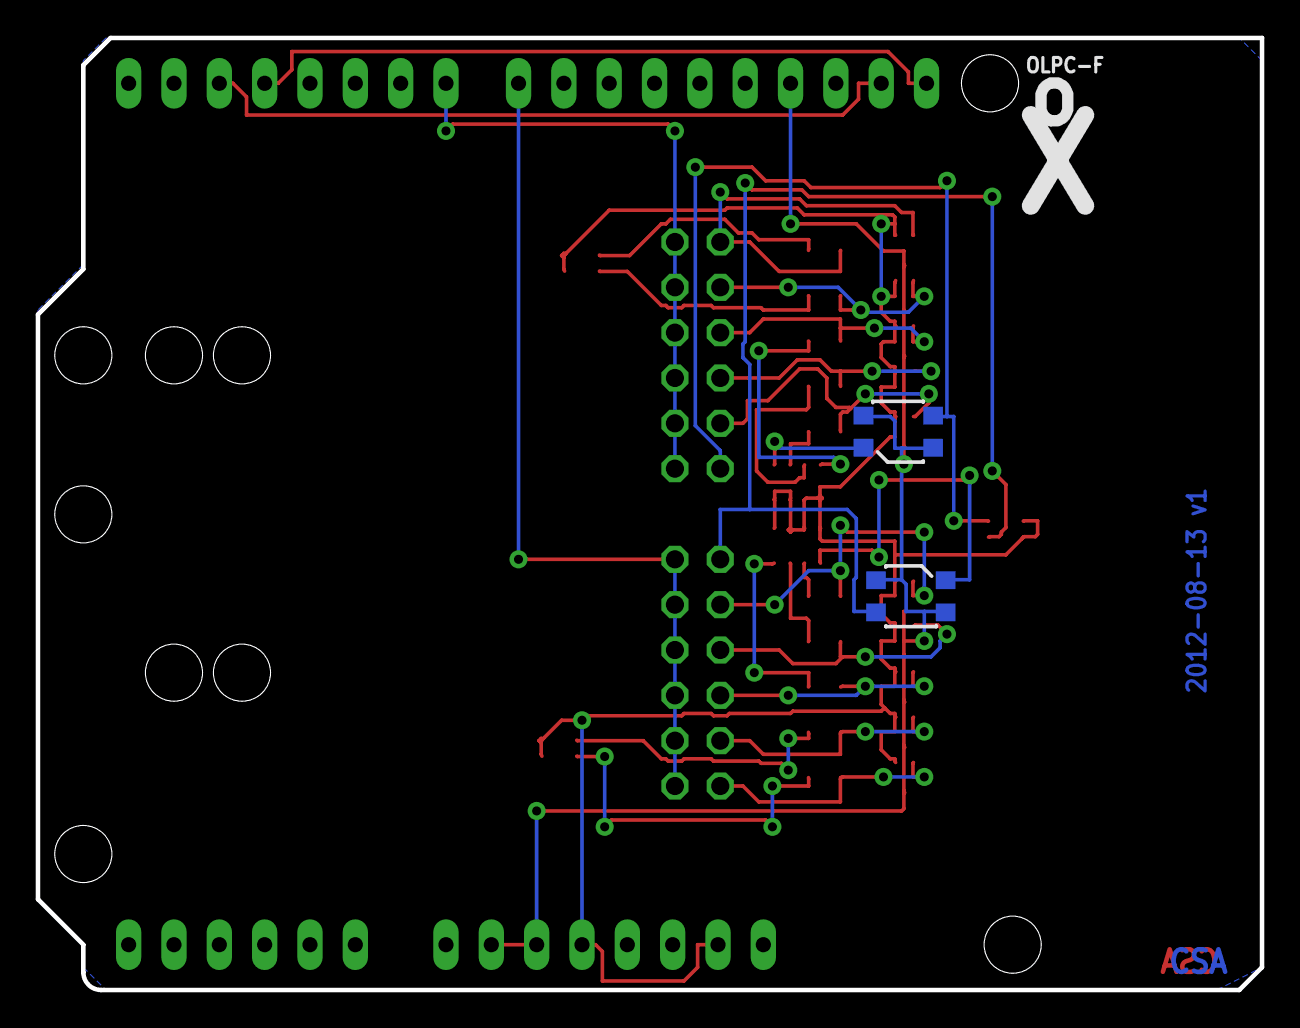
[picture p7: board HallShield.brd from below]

Board: 4 copper layers, 68.6 x 53.3 mm, 34 parts (2 on the bottom side), 30 nets.

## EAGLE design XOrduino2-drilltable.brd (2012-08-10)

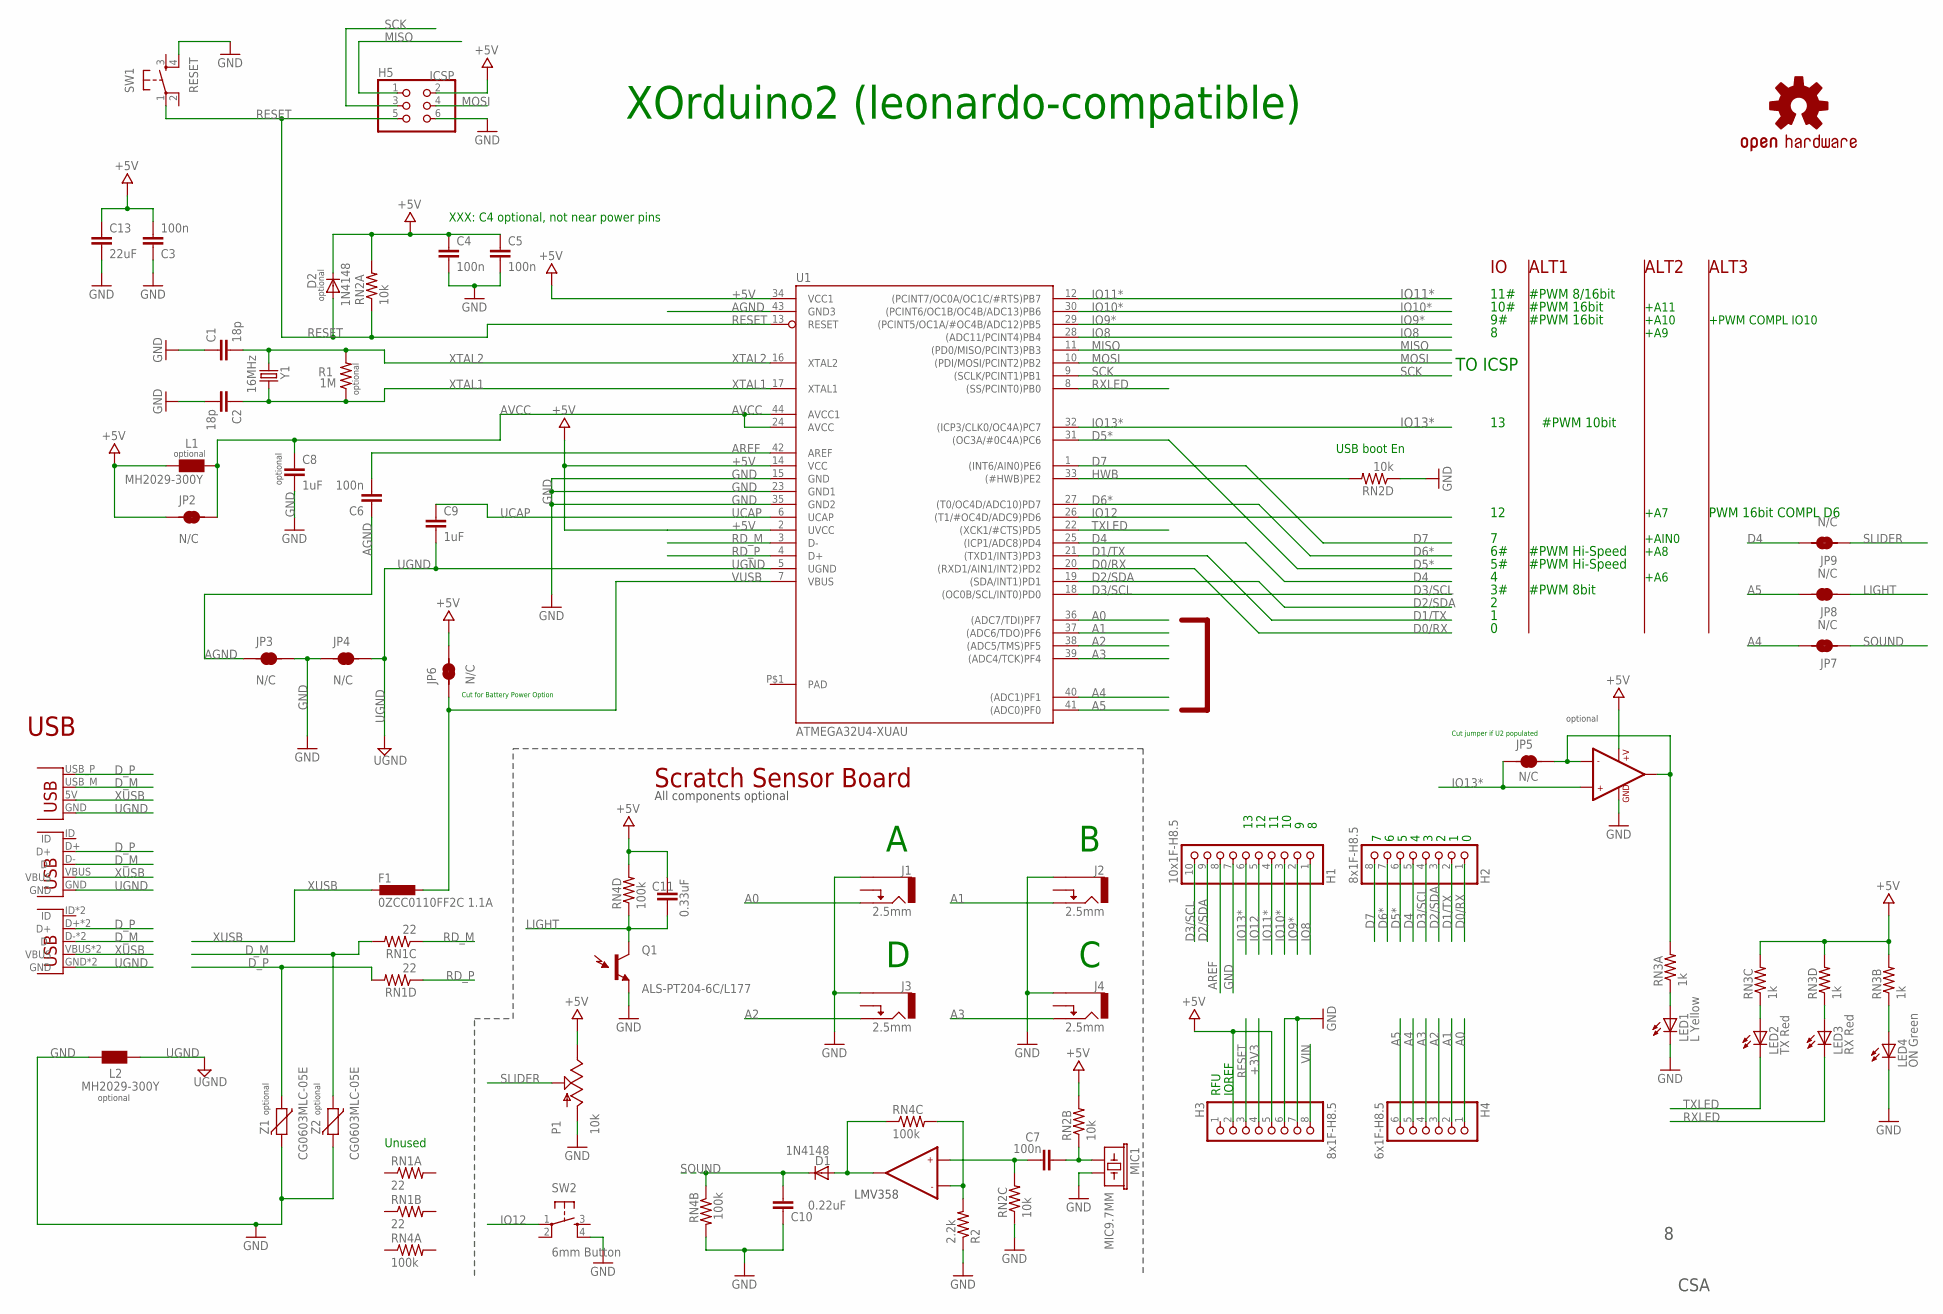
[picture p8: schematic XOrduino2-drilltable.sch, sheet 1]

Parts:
C1, C2: 18p; 0805
C3, C4, C5, C6, C7: 100n; 0805
C8, C9: 1uF; 0805
C10: 0.22uF; 0805
C11: 0.33uF; 0805
C13: 22uF; 1206
D1, D2: 1N4148; DIODE-1N4148
F1: 0ZCC0110FF2C 1.1A; L1812
H1: 10x1F-H8.5; 1X10
H2, H3: 8x1F-H8.5; 1X08
H4: 6x1F-H8.5; 1X06
H5: ICSP; 2X03
J1, J2, J3, J4: 2.5mm; MJ-3523-SMT
JP2, JP3, JP4, JP5, JP6: N/C; SJ-2S-TRACE-NOCONFLICT
JP7, JP8: N/C; SJ-2S-BOT-TRACE-VIA-NOCONFLICT
JP9: N/C; SJ-2S-BOT-TRACE-NOCONFLICT
L1, L2: MH2029-300Y; 0805
LED1: L Yellow; LED0805
LED2: TX Red; LED0805
LED3: RX Red; LED0805
LED4: ON Green; LED0805
MIC1: MIC9.7MM; MIC-9.7MM
P1: 10k; P091N
Q1: ALS-PT204-6C/L177; LED3MM-KIT
R1: 1M; 0805
R2: 2.2k; 0805
RN1: 22; CRA06S
RN2: 10k; CRA06S
RN3: 1k; CRA06S
RN4: 100k; CRA06S
SW1: RESET; TACTILE-PTH
SW2: 6mm Button; TACTILE-PTH
U1: ATMEGA32U4-XUAU; TQFP44-PAD
U2: LMV358; SO08
U$5: OSHW-LOGOL; OSHW-LOGO-L
X1: USBPCB; USB-A-PCB
X2: USBMINIB; USB-MB-H2
X3: USBMICROB-VIA; USB-MICROB-VIA
Y1: 16MHz; HC49US
Z1, Z2: CG0603MLC-05E; CT/CN0603

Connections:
+3V3: H3.4
+5V: C3.2, C4.1, C5.1, C11.1, C13.1, D2.C, H3.2, H3.5, H5.2, JP2.1, JP6.2, L1.1, P1.1 (E), RN2.7 (2), RN2.8 (2), RN3.5 (2), RN3.6 (2), RN3.7 (2), RN4.5 (2), U1.2 (UVCC), U1.14 (VCC), U1.34 (VCC1), U2.8 (+V); also elsewhere on the board
A0: H4.1, J1.2 (TIP), U1.36 ((ADC7/TDI)PF7)
A1: H4.2, J2.2 (TIP), U1.37 ((ADC6/TDO)PF6)
A2: H4.3, J3.2 (TIP), U1.38 ((ADC5/TMS)PF5)
A3: H4.4, J4.2 (TIP), U1.39 ((ADC4/TCK)PF4)
A4: H4.5, JP7.2, U1.40 ((ADC1)PF1)
A5: H4.6, JP8.2, U1.41 ((ADC0)PF0)
AGND: C6.1, JP3.1, U1.43 (GND3)
AREF: C6.2, H1.8, U1.42 (AREF)
AVCC: C8.1, JP2.2, L1.2, U1.24 (AVCC), U1.44 (AVCC1)
D0/RX: H2.1, U1.20 ((RXD1/AIN1/INT2)PD2); also elsewhere on the board
D1/TX: H2.2, U1.21 ((TXD1/INT3)PD3); also elsewhere on the board
D2/SDA: H1.9, H2.3, U1.19 ((SDA/INT1)PD1); also elsewhere on the board
D3/SCL: H1.10, H2.4, U1.18 ((OC0B/SCL/INT0)PD0)
D4: H2.5, JP9.2, U1.25 ((ICP1/ADC8)PD4)
D5*: H2.6, U1.31 ((OC3A/#0C4A)PC6); also elsewhere on the board
D6*: H2.7, U1.27 ((T0/OC4D/ADC10)PD7); also elsewhere on the board
D7: H2.8, U1.1 ((INT6/AIN0)PE6); also elsewhere on the board
D_M: RN1.6 (2), X1.USB_M (D-), X2.D-, X3.D-, X3.D-_VIA (D-), Z2.1
D_P: RN1.5 (2), X1.USB_P (D+), X2.D+, X3.D+, X3.D+_VIA (D+), Z1.1
GND: C1.1, C2.2, C3.1, C4.2, C5.2, C8.2, C10.1, C13.2, H1.7, H3.6, H3.7, H5.6, J1.1 (SLEEVE), J2.1 (SLEEVE), J3.1 (SLEEVE), J4.1 (SLEEVE), JP3.2, JP4.1, L2.2, LED1.C, LED4.C, MIC1.2, P1.3 (A), Q1.A (E1), R2.1, RN2.3 (1), RN2.4 (1), RN4.7 (2), SW1.4, SW2.4, U1.15 (GND), U1.23 (GND1), U1.35 (GND2), U2.4 (GND), Z1.2, Z2.2; also elsewhere on the board
HWB: RN2.5 (2), U1.33 ((#HWB)PE2)
IO8: H1.1, U1.28 ((ADC11/PCINT4)PB4); also elsewhere on the board
IO9*: H1.2, U1.29 ((PCINT5/OC1A/#OC4B/ADC12)PB5); also elsewhere on the board
IO10*: H1.3, U1.30 ((PCINT6/OC1B/OC4B/ADC13)PB6); also elsewhere on the board
IO11*: H1.4, U1.12 ((PCINT7/OC0A/OC1C/#RTS)PB7); also elsewhere on the board
IO12: H1.5, SW2.1, U1.26 ((T1/#OC4D/ADC9)PD6)
IO13*: H1.6, JP5.1, U1.32 ((ICP3/CLK0/OC4A)PC7), U2.3 (+IN1)
IO13_MIRROR: JP5.2, RN3.8 (2), U2.1 (OUT1), U2.2 (-IN1)
LED1_ANODE: LED1.A, RN3.1
LED2_ANODE: LED2.A, RN3.3 (1)
LED3_ANODE: LED3.A, RN3.4 (1)
LED4_ANODE: LED4.A, RN3.2 (1)
LIGHT: C11.2, JP8.1, JP8.VIA6 (1), Q1.K (C1), RN4.4 (1)
MIC_IN: C7.1, MIC1.1, RN2.2 (1)
MISO: H5.1, U1.11 ((PD0/MISO/PCINT3)PB3)
MOSI: H5.4, U1.10 ((PDI/MOSI/PCINT2)PB2)
OPAMP1_M: R2.2, RN4.6 (2), U2.6 (-IN2)
OPAMP1_OUT: D1.A, RN4.3 (1), U2.7 (OUT2)
OPAMP1_P: C7.2, RN2.6 (2), U2.5 (+IN2)
PAD: U1.P$1 (PAD)
RD_M: RN1.3 (1), U1.3 (D-)
RD_P: RN1.4 (1), U1.4 (D+)
RESET: D2.A, H3.3, H5.5, RN2.1, SW1.1, U1.13 (RESET)
RXLED: LED3.C, U1.8 ((SS/PCINT0)PB0)
SCK: H5.3, U1.9 ((SCLK/PCINT1)PB1)
SLIDER: JP9.1, P1.2 (S)
SOUND: C10.2, D1.C, JP7.1, JP7.VIA6 (1), RN4.2 (1)
TXLED: LED2.C, U1.22 ((XCK1/#CTS)PD5)
UCAP: C9.1, U1.6 (UCAP)
UGND: C9.2, JP4.2, L2.1, U1.5 (UGND), X1.GND, X2.GND, X3.GND, X3.GND_VIA (GND)
VIN: H3.8; also elsewhere on the board
VUSB: F1.1, JP6.1, U1.7 (VBUS); also elsewhere on the board
XTAL1: C2.1, R1.1, U1.17 (XTAL1), Y1.2
XTAL2: C1.2, R1.2, U1.16 (XTAL2), Y1.1
XUSB: F1.2, X1.5V (VBUS), X2.VBUS, X3.VBUS, X3.VBUS_VIA (VBUS)

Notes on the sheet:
XOrduino2 (leonardo-compatible)
USB boot En
USB
TO ICSP
10#
11#
#PWM 8bit
#PWM Hi-Speed
#PWM 8/16bit
#PWM 16bit
PWM 16bit COMPL D6
#PWM 10bit
+A6
+A7
IOREF
RFU
+A11
+A10
+A8
+A9
+PWM COMPL IO10
+AIN0
ALT1
ALT2
ALT3
optional
CSA
Scratch Sensor Board
LMV358
All components optional
Cut for Battery Power Option
Cut jumper if U2 populated
Unused
XXX: C4 optional, not near power pins

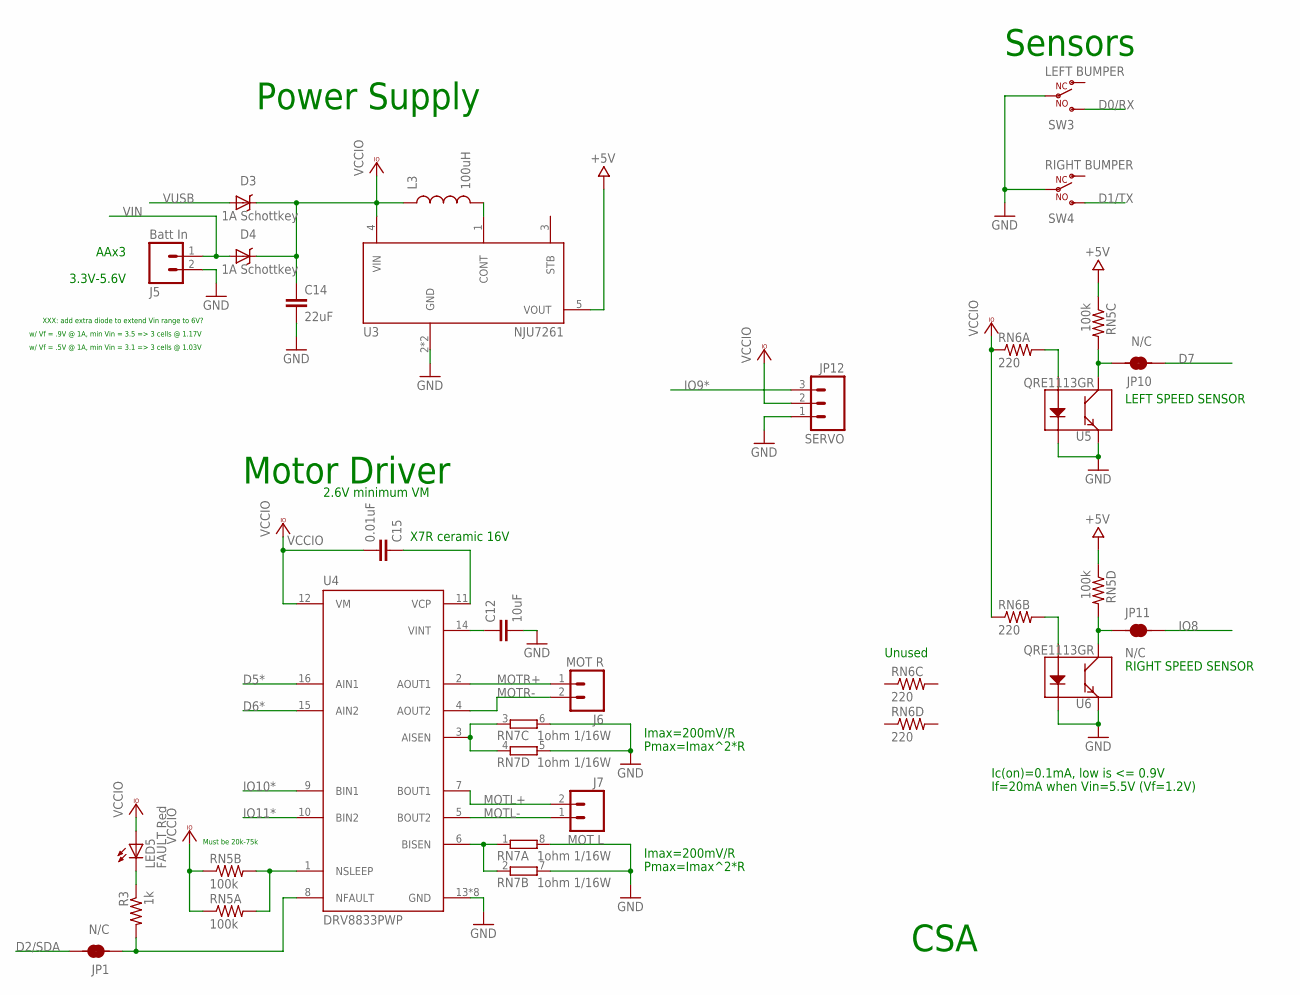
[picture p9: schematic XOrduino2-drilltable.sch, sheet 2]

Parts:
C12: 10uF; 0805
C14: 22uF; 1206
C15: 0.01uF; 0805
D3, D4: 1A Schottkey; SMA-DIODE
J5: Batt In; 1X02
J6: MOT R; SCREWTERMINAL-3.5MM-2
J7: MOT L; SCREWTERMINAL-3.5MM-2
JP1: N/C; SJ-2S-TRACE-NOCONFLICT
JP10, JP11: N/C; SJ-2S-BOT-TRACE-VIA-NOCONFLICT
JP12: SERVO; 1X03
L3: 100uH; 1007
LED5: FAULT Red; LED0805
R3: 1k; 0805
RN5: 100k; CRA06S
RN6: 220; CRA06S
RN7: 1ohm 1/16W; EXB38V
SW3: LEFT BUMPER; SW-LEVER-V1-NOHOLES
SW4: RIGHT BUMPER; SW-LEVER-V2-NOHOLES
U3: NJU7261; SOT89-5
U4: DRV8833PWP; PWP16
U5, U6: QRE1113GR

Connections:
+5V: RN5.3 (1), RN5.4 (1), U3.5 (VOUT); also elsewhere on the board
D0/RX: SW3.NO; also elsewhere on the board
D1/TX: SW4.NO; also elsewhere on the board
D2/SDA: JP1.2; also elsewhere on the board
D5*: U4.16 (AIN1); also elsewhere on the board
D6*: U4.15 (AIN2); also elsewhere on the board
D7: JP10.1, JP10.VIA6 (1); also elsewhere on the board
GND: C12.2, C14.2, J5.2, JP12.1, RN7.5 (2), RN7.6 (2), RN7.7 (2), RN7.8 (2), SW3.C, SW4.C, U3.2 (GND), U3.VIA1 (GND), U4.13 (GND), U4.PPAD (GND), U4.VIA1 (GND), U4.VIA2 (GND), U4.VIA3 (GND), U4.VIA4 (GND), U4.VIA5 (GND), U4.VIA6 (GND), U5.2 (K), U5.4 (E), U6.2 (K), U6.4 (E); also elsewhere on the board
IO8: JP11.2; also elsewhere on the board
IO9*: JP12.3; also elsewhere on the board
IO10*: U4.9 (BIN1); also elsewhere on the board
IO11*: U4.10 (BIN2); also elsewhere on the board
LED5_CATHODE: LED5.C, R3.1
MOTL+: J7.2, U4.7 (BOUT1)
MOTL-: J7.1, U4.5 (BOUT2)
MOTR+: J6.1, U4.2 (AOUT1)
MOTR-: J6.2, U4.4 (AOUT2)
U3_CONT: L3.2, U3.1 (CONT)
U4_AISEN: RN7.3 (1), RN7.4 (1), U4.3 (AISEN)
U4_BISEN: RN7.1, RN7.2 (1), U4.6 (BISEN)
U4_NFAULT: JP1.1, R3.2, U4.8 (NFAULT)
U4_NSLEEP: RN5.7 (2), RN5.8 (2), U4.1 (NSLEEP)
U4_VCP: C15.1, U4.11 (VCP)
U4_VINT: C12.1, U4.14 (VINT)
U5_ANODE: RN6.8 (2), U5.1 (A)
U5_COLLECTOR: JP10.2, RN5.6 (2), U5.3 (C)
U6_ANODE: RN6.7 (2), U6.1 (A)
U6_COLLECTOR: JP11.1, JP11.VIA6 (1), RN5.5 (2), U6.3 (C)
VCCIO: C14.1, C15.2, D3.C, D4.C, JP12.2, L3.1, LED5.A, RN5.1, RN5.2 (1), RN6.1, RN6.2 (1), U3.4 (VIN), U4.12 (VM)
VIN: D4.A, J5.1; also elsewhere on the board
VUSB: D3.A; also elsewhere on the board

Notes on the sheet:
Imax=200mV/R
Pmax=Imax^2*R
LEFT SPEED SENSOR
RIGHT SPEED SENSOR
If=20mA when Vin=5.5V (Vf=1.2V)
Ic(on)=0.1mA, low is <= 0.9V
AAx3
3.3V-5.6V
Motor Driver
Power Supply
Sensors
XXX: add extra diode to extend Vin range to 6V?
2.6V minimum VM
w/ Vf = .9V @ 1A, min Vin = 3.5 => 3 cells @ 1.17V
w/ Vf = .5V @ 1A, min Vin = 3.1 => 3 cells @ 1.03V
X7R ceramic 16V
Unused
Must be 20k-75k
CSA

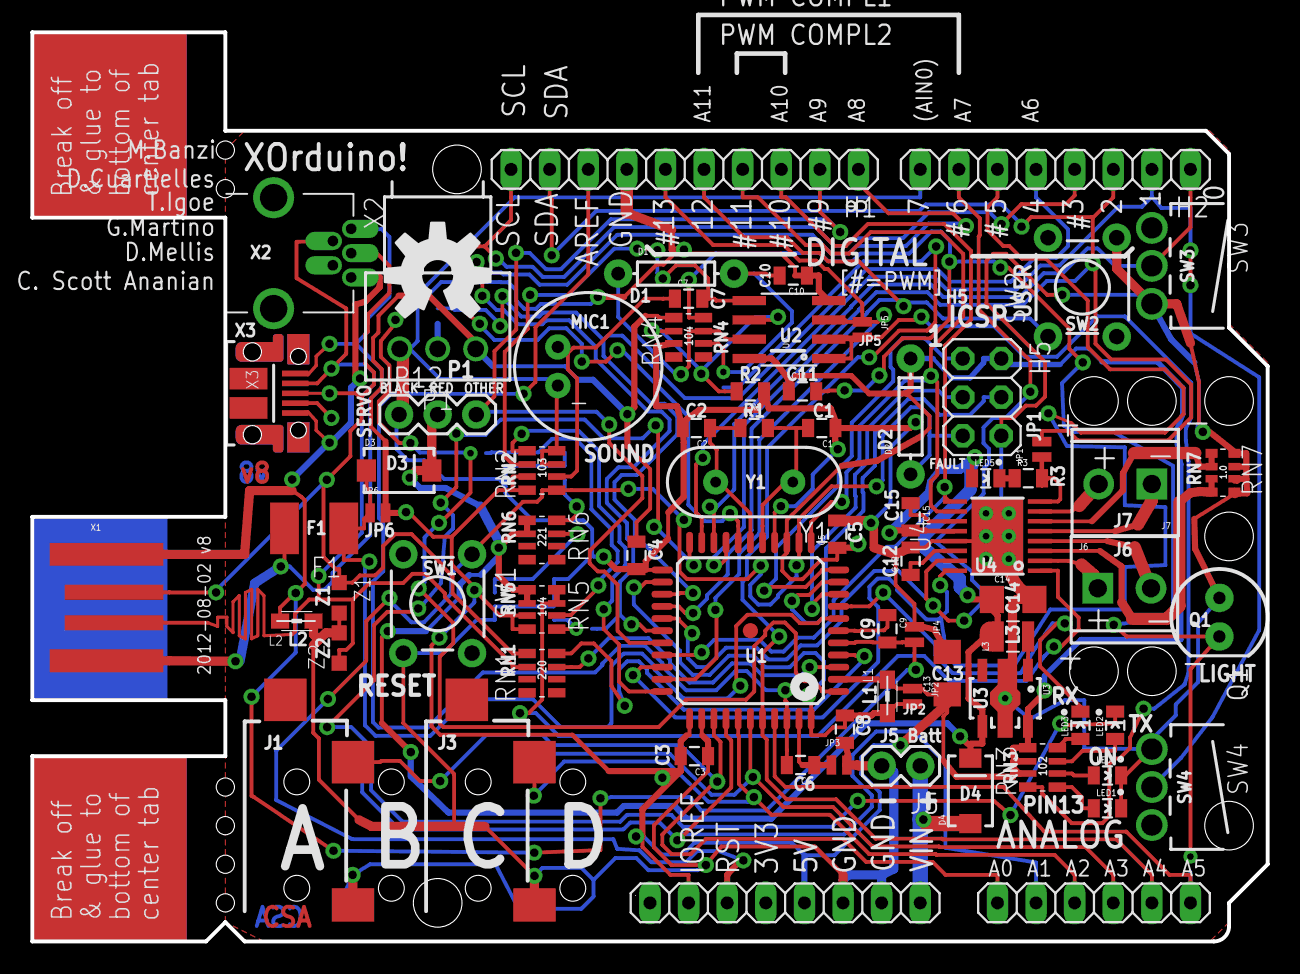
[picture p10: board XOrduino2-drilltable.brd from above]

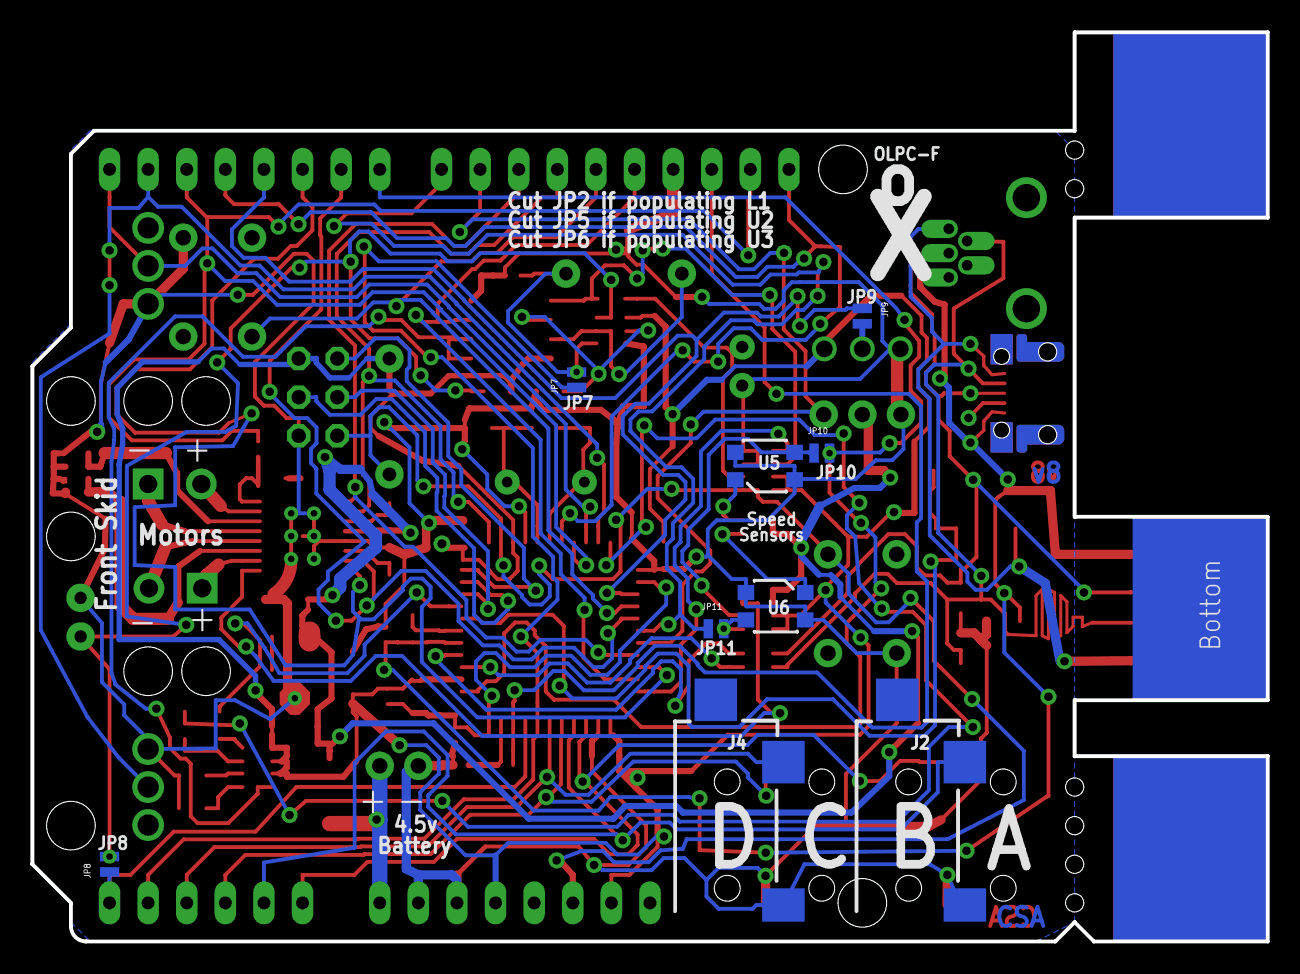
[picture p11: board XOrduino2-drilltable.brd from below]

Board: 4 copper layers, 81.3 x 59.8 mm, 83 parts (4 on the bottom side), 72 nets.

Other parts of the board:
DRILEGEND: DRILEGEND

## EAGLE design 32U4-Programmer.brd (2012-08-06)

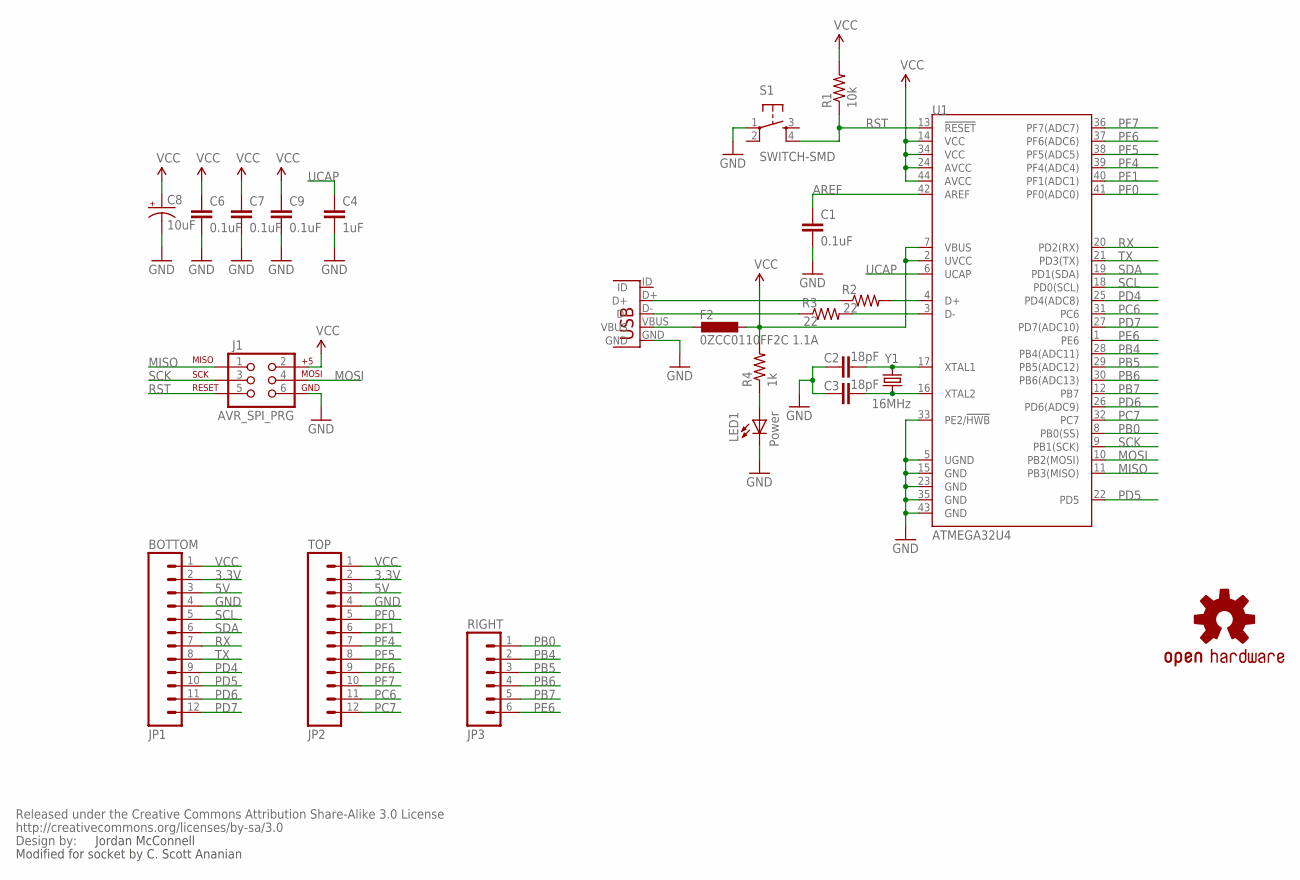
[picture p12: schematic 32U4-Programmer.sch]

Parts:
C1, C6, C7, C9: 0.1uF; CAP-PTH-SMALL
C2, C3: 18pF; CAP-PTH-SMALL
C4: 1uF; CAP-PTH-SMALL
C8: 10uF; CPOL-RADIAL-10UF-25V
F2: 0ZCC0110FF2C 1.1A; L1812
J1: AVR_SPI_PRG; 2X3
JP1: BOTTOM; 1X12
JP2: TOP; 1X12
JP3: RIGHT; 1X06
LED1: Power; LED3MM-KIT
R1: 10k; AXIAL-0.3
R2, R3: 22; AXIAL-0.3
R4: 1k; AXIAL-0.3
S1: SWITCH-SMD; TACTILE-PTH
U1: ATMEGA32U4; TQFP44-SOCKET
U$6: OSHW-LOGOM; OSHW-LOGO-M
U$7: CREATIVE_COMMONS
X1: USBMINIB; USB-MB-H2
Y1: 16MHz; HC49US

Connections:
3.3V: JP1.2, JP2.2
5V: JP1.3, JP2.3
AREF: C1.1, U1.42 (AREF)
D_M: R3.P$1 (1), X1.D-
D_P: R2.P$1 (1), X1.D+
GND: C1.2, C2.1, C3.1, C4.2, C6.2, C7.2, C8.2 (-), C9.2, J1.6, JP1.4, JP2.4, LED1.K (C), S1.1, U1.5 (UGND), U1.15 (GND), U1.23 (GND), U1.33 (PE2/!HWB), U1.35 (GND), U1.43 (GND), X1.GND
MISO: J1.1, U1.11 (PB3(MISO))
MOSI: J1.4, U1.10 (PB2(MOSI))
unnamed: F2.2, X1.VBUS
unnamed: C2.2, U1.17 (XTAL1), Y1.2
unnamed: C3.2, U1.16 (XTAL2), Y1.1
unnamed: LED1.A, R4.P$1 (1)
PB0: JP3.1, U1.8 (PB0(SS))
PB4: JP3.2, U1.28 (PB4(ADC11))
PB5: JP3.3, U1.29 (PB5(ADC12))
PB6: JP3.4, U1.30 (PB6(ADC13))
PB7: JP3.5, U1.12 (PB7)
PC6: JP2.11, U1.31 (PC6)
PC7: JP2.12, U1.32 (PC7)
PD4: JP1.9, U1.25 (PD4(ADC8))
PD5: JP1.10, U1.22 (PD5)
PD6: JP1.11, U1.26 (PD6(ADC9))
PD7: JP1.12, U1.27 (PD7(ADC10))
PE6: JP3.6, U1.1 (PE6)
PF0: JP2.5, U1.41 (PF0(ADC0))
PF1: JP2.6, U1.40 (PF1(ADC1))
PF4: JP2.7, U1.39 (PF4(ADC4))
PF5: JP2.8, U1.38 (PF5(ADC5))
PF6: JP2.9, U1.37 (PF6(ADC6))
PF7: JP2.10, U1.36 (PF7(ADC7))
RD_M: R3.P$2 (2), U1.3 (D-)
RD_P: R2.P$2 (2), U1.4 (D+)
RST: J1.5, R1.P$1 (1), S1.4, U1.13 (!RESET)
RX: JP1.7, U1.20 (PD2(RX))
SCK: J1.3, U1.9 (PB1(SCK))
SCL: JP1.5, U1.18 (PD0(SCL))
SDA: JP1.6, U1.19 (PD1(SDA))
TX: JP1.8, U1.21 (PD3(TX))
UCAP: C4.1, U1.6 (UCAP)
VCC: C6.1, C7.1, C8.1 (+), C9.1, F2.1, J1.2, JP1.1, JP2.1, R1.P$2 (2), R4.P$2 (2), U1.2 (UVCC), U1.7 (VBUS), U1.14 (VCC), U1.24 (AVCC), U1.34 (VCC), U1.44 (AVCC)

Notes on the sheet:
Jordan McConnell
Modified for socket by C. Scott Ananian

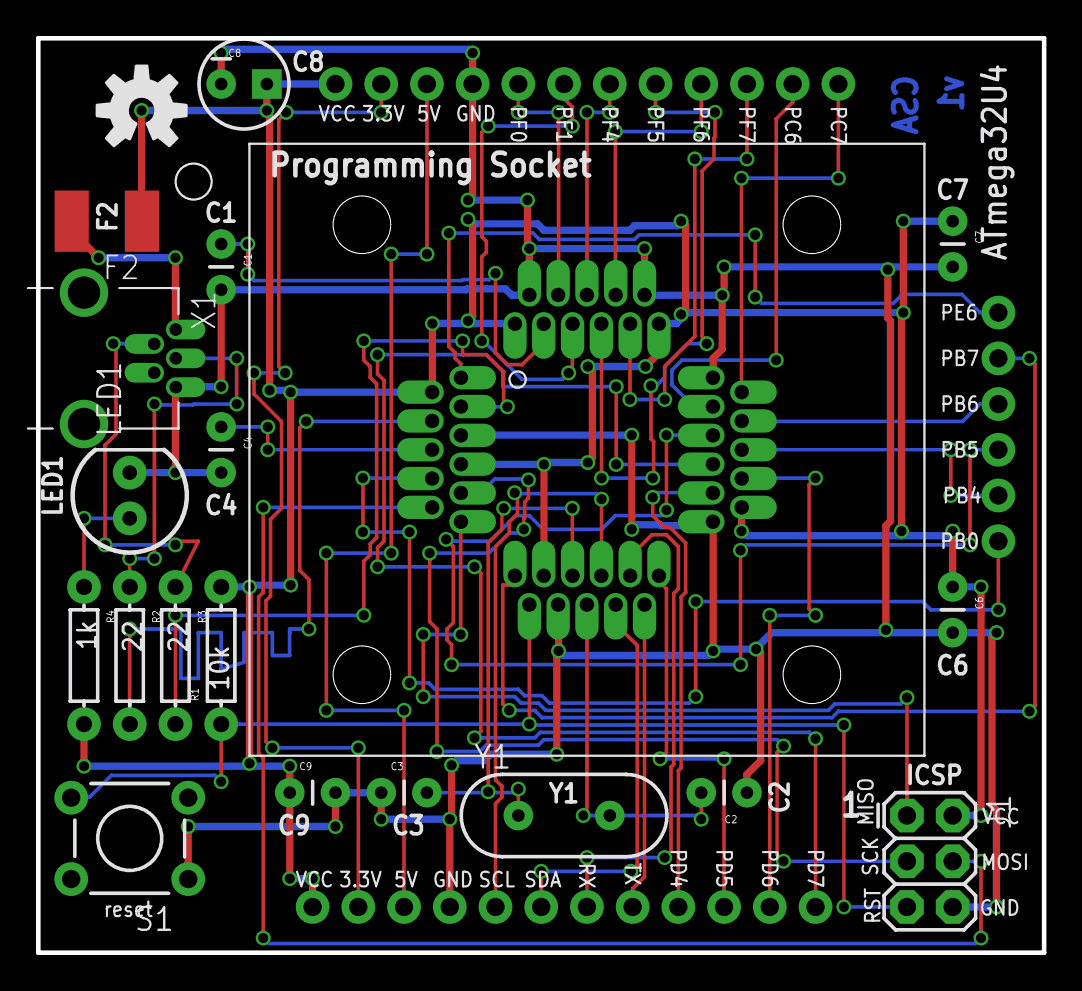
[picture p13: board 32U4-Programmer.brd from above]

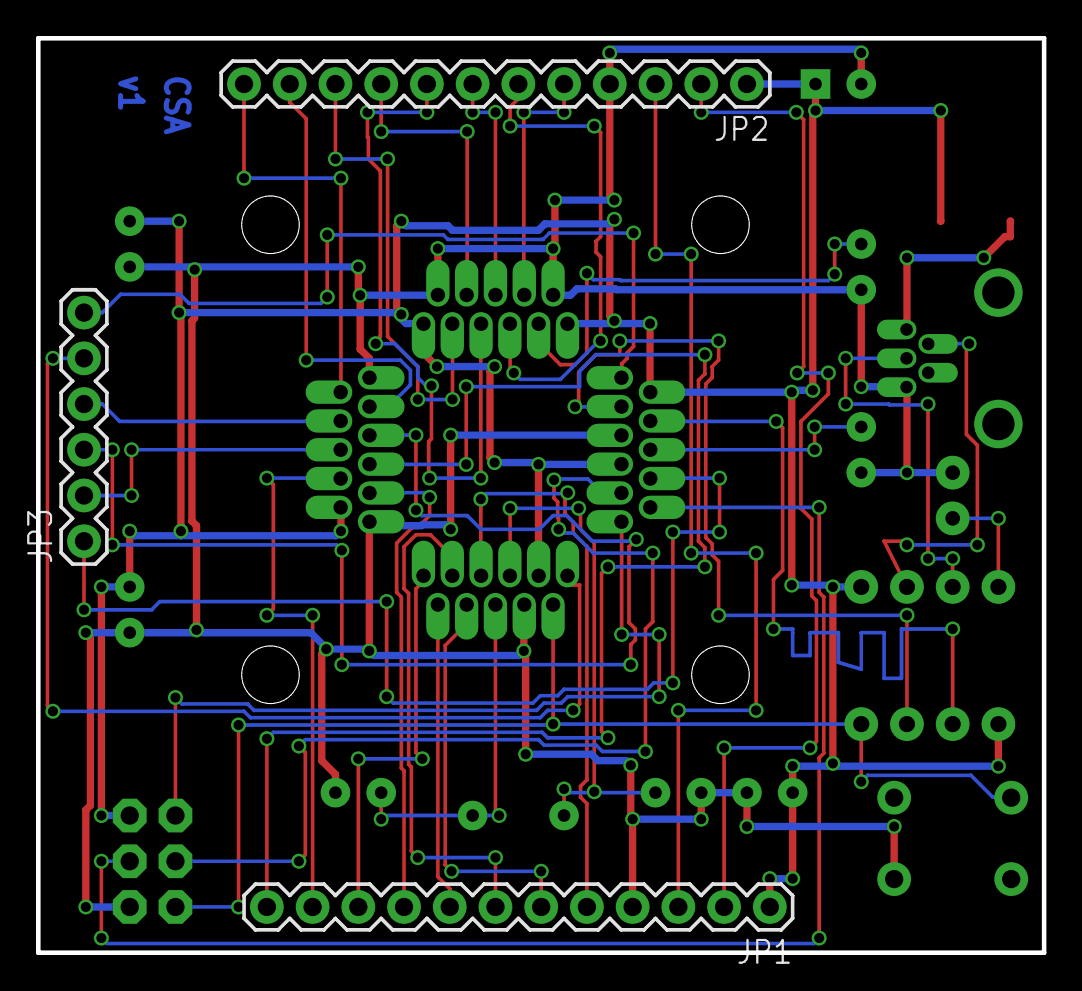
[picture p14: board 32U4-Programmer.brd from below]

Board: 2 copper layers, 55.9 x 50.8 mm, 24 parts (3 on the bottom side), 40 nets.

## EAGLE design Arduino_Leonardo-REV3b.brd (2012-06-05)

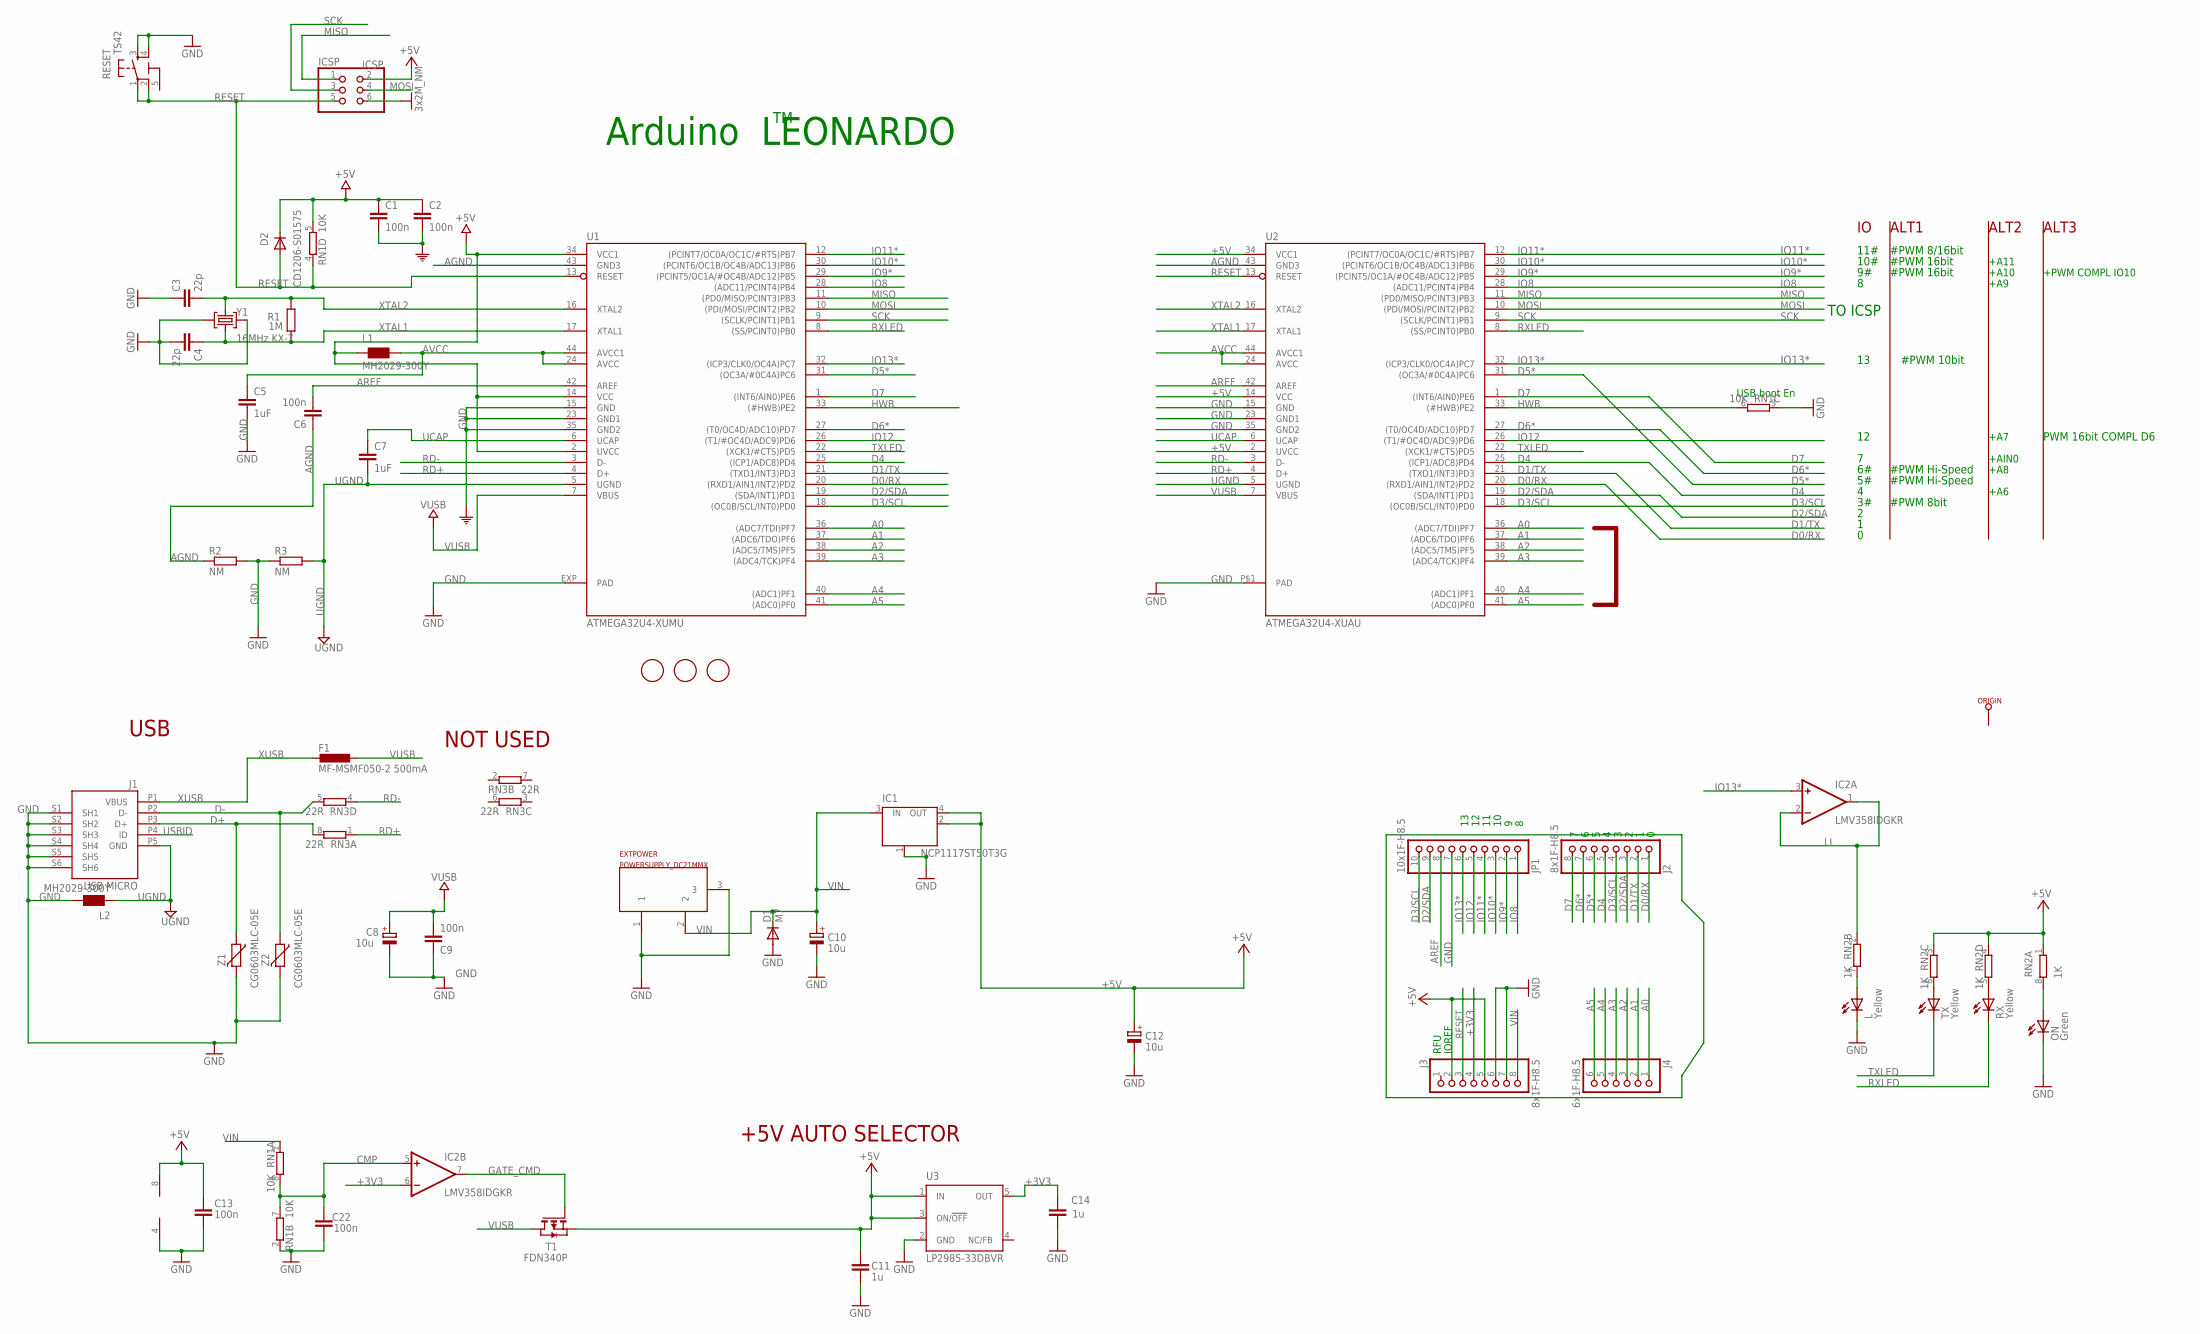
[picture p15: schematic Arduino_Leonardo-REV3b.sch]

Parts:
C1, C2, C6, C9, C13, C22: 100n; C0603-ROUND
C3, C4: 22p; C0603-ROUND
C5, C7: 1uF; C0603-ROUND
C8, C10, C12: 10u; SMC_B
C11, C14: 1u; C0603-ROUND
D1: M7; SMB
D2: CD1206-S01575; MINIMELF
EXTPOWER: POWERSUPPLY_DC21MMX; POWERSUPPLY_DC-21MM
F1: MF-MSMF050-2 500mA; L1812
FID1, FID2, FID3: FIDUCIALMOUNT; FIDUCIA-MOUNT
IC1: NCP1117ST50T3G; SOT223
IC2: LMV358IDGKR; MSOP08
ICSP: ICSP; 2X03
J1: USB MICRO; CON2_USB_MICRO_B_AT
J2, J3: 8x1F-H8.5; 1X08
J4: 6x1F-H8.5; 1X06
JP1: 10x1F-H8.5; 1X10
L: Yellow; CHIPLED_0805
L1, L2: MH2029-300Y; 0805
ON: Green; CHIPLED_0805
ORIGIN: TP_SP; TP-SP
R1: 1M; R0603-ROUND
R2, R3: NM; R0402
RESET: TS42
RN1: 10K; CAY16
RN2: 1K; CAY16
RN3: 22R; CAY16
RX: Yellow; CHIPLED_0805
T1: FDN340P; SOT-23
TX: Yellow; CHIPLED_0805
U1: ATMEGA32U4-XUMU; QFN44ML7X7
U2: ATMEGA32U4-XUAU; TQFP44-PAD
U3: LP2985-33DBVR; SOT23-DBV
Y1: 16MHz KX-7; CRYSTAL-3.2-2.5
Z1, Z2: CG0603MLC-05E; CT/CN0603

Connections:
5-GND: RESET.5 (5-GND)
+3V3: C14.2, IC2.6 (-IN), J3.4, U3.5 (OUT)
+5V: C1.1, C2.1, C11.2, C12.+, C13.1, D2.C, IC1.2 (OUT), IC1.4 (OUT), IC2.8 (V+), ICSP.2, J3.2, J3.5, L1.1, RN1.5 (2), RN2.1, RN2.3 (1), RN2.4 (1), T1.2 (S), U1.2 (UVCC), U1.14 (VCC), U1.34 (VCC1), U2.2 (UVCC), U2.14 (VCC), U2.34 (VCC1), U3.1 (IN), U3.3 (ON/!OFF)
A0: J4.1, U1.36 ((ADC7/TDI)PF7), U2.36 ((ADC7/TDI)PF7)
A1: J4.2, U1.37 ((ADC6/TDO)PF6), U2.37 ((ADC6/TDO)PF6)
A2: J4.3, U1.38 ((ADC5/TMS)PF5), U2.38 ((ADC5/TMS)PF5)
A3: J4.4, U1.39 ((ADC4/TCK)PF4), U2.39 ((ADC4/TCK)PF4)
A4: J4.5, U1.40 ((ADC1)PF1), U2.40 ((ADC1)PF1)
A5: J4.6, U1.41 ((ADC0)PF0), U2.41 ((ADC0)PF0)
AGND: C6.1, R2.1, U1.43 (GND3), U2.43 (GND3)
AREF: C6.2, JP1.8, U1.42 (AREF), U2.42 (AREF)
AVCC: C5.1, L1.2, U1.24 (AVCC), U1.44 (AVCC1), U2.24 (AVCC), U2.44 (AVCC1)
CMP: C22.2, IC2.5 (+IN), RN1.7 (2), RN1.8 (2)
D0/RX: J2.1, U1.20 ((RXD1/AIN1/INT2)PD2), U2.20 ((RXD1/AIN1/INT2)PD2)
D1/TX: J2.2, U1.21 ((TXD1/INT3)PD3), U2.21 ((TXD1/INT3)PD3)
D2/SDA: J2.3, JP1.9, U1.19 ((SDA/INT1)PD1), U2.19 ((SDA/INT1)PD1)
D3/SCL: J2.4, JP1.10, U1.18 ((OC0B/SCL/INT0)PD0), U2.18 ((OC0B/SCL/INT0)PD0)
D4: J2.5, U1.25 ((ICP1/ADC8)PD4), U2.25 ((ICP1/ADC8)PD4)
D5*: J2.6, U1.31 ((OC3A/#0C4A)PC6), U2.31 ((OC3A/#0C4A)PC6)
D6*: J2.7, U1.27 ((T0/OC4D/ADC10)PD7), U2.27 ((T0/OC4D/ADC10)PD7)
D7: J2.8, U1.1 ((INT6/AIN0)PE6), U2.1 ((INT6/AIN0)PE6)
D+: J1.P3 (D+), RN3.8 (2), Z1.1
D-: J1.P2 (D-), RN3.5 (2), Z2.1
GATE_CMD: IC2.7 (OUT), T1.3 (G)
GND: C1.2, C2.2, C3.1, C4.2, C5.2, C8.-, C9.1, C10.-, C11.1, C12.-, C13.2, C14.1, C22.1, D1.A, EXTPOWER.1, EXTPOWER.3, IC1.1 (GND/ADJ), IC2.4 (V-), ICSP.6, J1.S1 (SH1), J1.S2 (SH2), J1.S3 (SH3), J1.S4 (SH4), J1.S5 (SH5), J1.S6 (SH6), J3.6, J3.7, JP1.7, L.C, L2.2, ON.C, R2.2, R3.1, RESET.3, RESET.4, RN1.2 (1), RN1.3 (1), U1.15 (GND), U1.23 (GND1), U1.35 (GND2), U1.EXP (PAD), U2.15 (GND), U2.23 (GND1), U2.35 (GND2), U2.P$1 (PAD), U3.2 (GND), Y1.2 (GND), Y1.4 (GND), Z1.2, Z2.2
HWB: RN1.6 (2), U1.33 ((#HWB)PE2), U2.33 ((#HWB)PE2)
IO8: JP1.1, U1.28 ((ADC11/PCINT4)PB4), U2.28 ((ADC11/PCINT4)PB4)
IO9*: JP1.2, U1.29 ((PCINT5/OC1A/#OC4B/ADC12)PB5), U2.29 ((PCINT5/OC1A/#OC4B/ADC12)PB5)
IO10*: JP1.3, U1.30 ((PCINT6/OC1B/OC4B/ADC13)PB6), U2.30 ((PCINT6/OC1B/OC4B/ADC13)PB6)
IO11*: JP1.4, U1.12 ((PCINT7/OC0A/OC1C/#RTS)PB7), U2.12 ((PCINT7/OC0A/OC1C/#RTS)PB7)
IO12: JP1.5, U1.26 ((T1/#OC4D/ADC9)PD6), U2.26 ((T1/#OC4D/ADC9)PD6)
IO13*: IC2.3 (+IN), JP1.6, U1.32 ((ICP3/CLK0/OC4A)PC7), U2.32 ((ICP3/CLK0/OC4A)PC7)
LL: IC2.1 (OUT), IC2.2 (-IN), RN2.2 (1)
MISO: ICSP.1, U1.11 ((PD0/MISO/PCINT3)PB3), U2.11 ((PD0/MISO/PCINT3)PB3)
MOSI: ICSP.4, U1.10 ((PDI/MOSI/PCINT2)PB2), U2.10 ((PDI/MOSI/PCINT2)PB2)
unnamed: L.A, RN2.7 (2)
unnamed: ON.A, RN2.8 (2)
unnamed: RN2.6 (2), TX.A
unnamed: RN2.5 (2), RX.A
RD+: RN3.1, U1.4 (D+), U2.4 (D+)
RD-: RN3.4 (1), U1.3 (D-), U2.3 (D-)
RESET: D2.A, ICSP.5, J3.3, RESET.1, RESET.2, RN1.4 (1), U1.13 (RESET), U2.13 (RESET)
RXLED: RX.C, U1.8 ((SS/PCINT0)PB0), U2.8 ((SS/PCINT0)PB0)
SCK: ICSP.3, U1.9 ((SCLK/PCINT1)PB1), U2.9 ((SCLK/PCINT1)PB1)
TXLED: TX.C, U1.22 ((XCK1/#CTS)PD5), U2.22 ((XCK1/#CTS)PD5)
UCAP: C7.1, U1.6 (UCAP), U2.6 (UCAP)
UGND: C7.2, J1.P5 (GND), L2.1, R3.2, U1.5 (UGND), U2.5 (UGND)
USBID: J1.P4 (ID)
VIN: C10.+, D1.C, EXTPOWER.2, IC1.3 (IN), J3.8, RN1.1
VUSB: C8.+, C9.2, F1.1, T1.1 (D), U1.7 (VBUS), U2.7 (VBUS)
XTAL1: C4.1, R1.1, U1.17 (XTAL1), U2.17 (XTAL1), Y1.1 (C1)
XTAL2: C3.2, R1.2, U1.16 (XTAL2), U2.16 (XTAL2), Y1.3 (C2)
XUSB: F1.2, J1.P1 (VBUS)

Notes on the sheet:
Arduino LEONARDO
USB boot En
USB
+5V AUTO SELECTOR
NOT USED
TO ICSP
10#
11#
#PWM 8bit
#PWM Hi-Speed
#PWM 8/16bit
#PWM 16bit
PWM 16bit COMPL D6
#PWM 10bit
+A6
+A7
IOREF
RFU
+A11
+A10
+A8
+A9
+PWM COMPL IO10
+AIN0
ALT1
ALT2
ALT3



Board: 2 copper layers, 68.6 x 53.3 mm, 51 parts (2 on the bottom side), 51 nets.

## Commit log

2012-06-05 Initial checkin of inspirational designs.
    [32U4_Breakout-v11.brd, 32U4_Breakout-v11.sch, Arduino_Leonardo-REV3b.brd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]
2012-06-07 First draft of XOrduino schematic.
    [XOrduino-v1.brd, XOrduino-v1.sch]
2012-06-07 Color version of XOrdiuno schematic.
2012-06-07 Attempt to route the board. 90% routed; may need to go to 4 layer board.
    [XOrduino-v1.brd, XOrduino-v1.sch]
2012-06-07 First full layout for XOrduino. (v1)
    [XOrduino-v1.brd]
2012-06-07 XOrduino v2 -- move USB plug up a bit to allow XOstick to fit underneath.
    [XOrduino-v1.brd, XOrduino-v1.sch]
2012-06-07 Version 3: silkscreen improvements (no silkscreen off board)
    [XOrduino-v1.brd, XOrduino-v1.sch]
2012-06-07 Rename gerber zip so there's no confusion about what version it is.
2012-06-08 XOrduino v4. Updated silkscreen, shorting jumpers for sensor lines; tweak USB-B.
    [XOrduino-v1.brd, XOrduino-v1.sch]
2012-06-09 Rename XOrduino-v1 to XOrduino to avoid confusion.
    [XOrduino.brd, XOrduino.sch]
2012-06-09 Update BOM for v4; classify components, add some pricing information.
2012-06-10 Update BOM (fill in more digikey part numbers and prices).
2012-06-20 Include solder paste layers in the gerber .zip, just in case that's useful.
2012-07-15 Update BOM, notes on v4 design based on 1st assembly of boards from OEM.
2012-07-18 Updated BOM for XOrduino and XOstick (A1 version).
2012-07-18 First commit of 'XOrdiuno2' redesign (turtle robot capable).
    Main changes in XOrduino2: integration of motor driver, bump switches,
    optical sensor, and battery/external power supply. In addition, various
    fixes found necessary on XOrduino v4 boards (ie with Scratch Sensor Board
    functionality). I'm also investigating a broader switch to SMT devices,
    for cost and space reasons. The XO Stick will remain a through-hole
    design; XOrduino may become an 'easy' SMT kit.
    [XOrduino2.brd, XOrduino2.sch]
2012-07-24 First version of Xorduino2 (v5) board w/ all components placed.
    [XOrduino2.brd, XOrduino2.sch]
2012-07-24 70% 2-layer routed version of XOrduino2.
    [XOrduino2.brd, XOrduino2.sch]
2012-07-25 Almost-completely 4-layer routed version of XOrduino2.
    [XOrduino2.brd, XOrduino2.sch]
2012-07-25 97% routed 4-layer XOrduino.
    [XOrduino2.brd, XOrduino2.sch]
2012-07-25 First fully-routed version of XOrduino2 (4-layer).
    [XOrduino2.brd]
2012-07-26 Tweaks for better 2-layer routability.
    [XOrduino2.brd, XOrduino2.sch]
2012-07-26 Best 2-layer XOrduino layout generated by Eagle.
    1mil grid, diagonal route direction preference, 95% routed.
    [XOrduino2.brd]
2012-07-27 Fully-routed 2-layer version of XOrduino. Thanks to freerouting.net.
    [XOrduino2.brd, XOrduino2.sch]
2012-07-28 v5 gerbers.
    [XOrduino2.brd, XOrduino2.sch]
2012-07-29 Attempt 2 at routing the XOrduino2 board, via 10mil traces & spaces this time.
    ...however, the router still doesn't have quite the right via clearances.
    [XOrduino2.brd]
2012-07-30 Xorduino v6: rerouting with bigger vias, 10 mil traces, and better spacing.
    Also added silkscreen, etc. and regenerated PDFs.
    [XOrduino2.brd, XOrduino2.sch]
2012-07-30 Clean up old A1 files to avoid confusion.
    [XOrduino.brd, XOrduino.sch]
2012-08-03 v7: Update USB mini-B footprint & bom; more heat sink area for motor driver.
    Went through and widened power traces as much as I could, as well.
    [XOrduino2.brd, XOrduino2.sch]
2012-08-03 Minor silkscreen tweaks, extend L3 pads a hair.
    [XOrduino2.brd, XOrduino2.sch]
2012-08-03 XOrduino2 v8. Rename nets for better manual auditing, silkscreen tweaks.
    [XOrduino2.brd, XOrduino2.sch]
2012-08-03 Update schematic and board PDFs.
2012-08-06 Programmer with ZIF socket for the ATmega32U4.
    [32U4-Programmer.brd, 32U4-Programmer.sch]
2012-08-10 Add drill table layer; regenerate Gerbers in vendor-approved format.
    The drill table was made with drillegend-stack.ulp. It has a problem deleting
    an existing drill table (see
    http://www.eaglecentral.ca/forums/index.php/mv/msg/46577/145423/
    ) so I've saved the .brd file with the drill legend as XOrduino2-drilltable.brd.
    If changes are necessary to XOrduino2.brd, regenerate XOrduino2-drilltable.brd
    from XOrduino2.brd after making the changes.
    [XOrduino2-drilltable.brd, XOrduino2-drilltable.sch]
2012-08-13 Hall Effect Sensor Test Shield, v1.
    [HallShield.brd, HallShield.sch]
2013-06-24 Chack in updated BOM for XOrduino2 v8 boards.
2013-06-24 Small updates to BOM.

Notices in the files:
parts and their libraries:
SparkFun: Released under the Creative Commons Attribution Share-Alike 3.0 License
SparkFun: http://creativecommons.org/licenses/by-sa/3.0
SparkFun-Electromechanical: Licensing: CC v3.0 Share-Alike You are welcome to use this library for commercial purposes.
